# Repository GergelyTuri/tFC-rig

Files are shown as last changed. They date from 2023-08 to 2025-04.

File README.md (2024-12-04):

# Open source trace fear conditioning apparatus for rodents

## Project Description

The ability to form declarative memories declines with normal aging, as well as with aging-associated cognitive and emotional disorders. Diminished temporal binding capacity, which normally allows for the association of non-overlapping stimuli and events in an experience, is a core process underlying such impairment with aging. This project will identify aging-associated alterations in brain activity functions supporting temporal binding capacity, with the long-term aim of identifying potential targets to slow or alleviate cognitive and emotional impairments in aging and aging-associated neuropsychiatric disorders.

The temporal binding of emotionally salient stimuli and events has long been studied experimentally using trace fear conditioning (tFC). Here, subjects learn to associate a neutral auditory cue (conditioned stimulus, CS) with an aversive unconditioned stimulus (US), despite their separation by a stimulus-free gap of tens of seconds. The ability to form associations across delays on this timescale during tFC is severely diminished with aging. Current models propose that either 'time cell' activity in the hippocampal CA1 area bridges the delay (1), or sparse ensembles of neurons emerge during learning to intermittently encode CS-information for temporal binding (2). However, the neural mechanisms underlying the age-related decline in temporal binding capacity remain unknown, giving rise to fundamental questions. What functional changes in neural activity occur with aging in the particular CA1 circuitry that encodes emotionally salient stimuli for temporal binding? What changes occur with aging in neural processes for consolidation of this information?

To address these questions we have developed a trace fear conditioning apparatus tailored for headfixed rodents. This rig has been engeineered to be both modular and flexible, allowing for easy customization and expansion. The rig is controlled by Arduino microcontrollers equipeed with sensors. The conditioning is done by airpuffs directed toward the snout of the animals. Multiple Arduinos can be used in a daisy-chain manner which allows for paralel data collection of multiple mice. The rigs can also be equipped with video cameras (currently sourced from [White Matter Inc.](https://white-matter.com/products/e3Vision)) to record the mice's facial expression throughout the training sessions. The data collection is controlled by a Python script that interfaces with the hardware via serial communication. The raw data is saved in JSON fromat.

## Repository Structure

The repository is organized as follows:

- The `Components` folder contains all the hardware designs for the rig. These include 3D printable parts, laser cuttable parts, and electronics schematics.
- the `Software` folder contains the Arduino code for the microcontrollers and the Python code for the data collection and analysis.
- the `Analysis` folder contains the code for the analysis of the data collected by the rig.

## Installation and Usage

### Arduino

The Arduino code is written in C++ and can be compiled and uploaded to the microcontrollers using the Arduino IDE. Details of the code are provided in the `README.md` file under the `Software/Rig` folder.

### Analysis source code

See the `README.md` file under the `Software/Analysis` folder for details on how to use the analysis pipeline.

## Local Development

Most of the analysis routies were optimized for running in Google Colaboratory notebooks. However the package can be installed for local development. To create it please download the latest Anaconda distribution. Then clone the repositioy and run the following commands as shown below:

```bash
cd tFC-rig
```

```bash
conda env create -f environment.yml
```

```bash
conda activate cued-fc
```

```bash
cd Analysis
```

```bash
pip install -e .
```

wich will install the custom analysis package in editable mode.

## References

1. Sellami A, Al Abed AS, Brayda-Bruno L, Etchamendy N, Valerio S, Oule M, Pantaleon L, Lamothe V,
Potier M, Bernard K, Jabourian M, Herry C, Mons N, Piazza PV, Eichenbaum H, Marighetto A. Temporal
binding function of dorsal CA1 is critical for declarative memory formation. [Proc Natl Acad Sci U S A.](https://www.pnas.org/doi/10.1073/pnas.1619657114)
2017;114(38):10262-7. doi: 10.1073/pnas.1619657114. PubMed PMID: 28874586; PMCID: PMC5617244.
2. Ahmed MS, Priestley JB, Castro A, Stefanini F, Canales ASS, Balough EM, Lavoie E, Mazzucato L, Fusi
S, Losonczy A. Hippocampal Network Reorganization Underlies the Formation of a Temporal Association
Memory. [Neuron.](https://pubmed.ncbi.nlm.nih.gov/32392472/) 2020;107(2):283-+. doi: 10.1016/j.neuron.2020.04.013. PubMed PMID:
WOS:000551381900002.

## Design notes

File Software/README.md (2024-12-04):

# Arduino Sketch for Performing Trace-Fear Conditioning

Graphical representation of the trace-fear conditioning protocol:

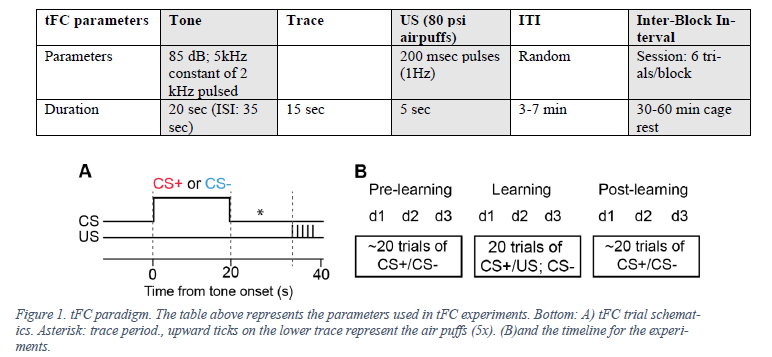
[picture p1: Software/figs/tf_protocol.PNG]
Trace-fear conditioning protocol


### Hardware Components

The Arduino controls the following components:

- 2 speakers which play two different tones (`CS+` and `CS-`)
- One water solenoid valve which delivers a water drop throughout the trial
- One air solenoid valve which delivers a series (5x) of airpuffs at the end of `CS+` the trial 
- Lickport which delivers a water drop when the mouse licks it

### The arduino records the following events:

- Times the mouse licks the lickometer

The trials make up blocks. 
One block consists of 3 trials of `CS+` and 3 trials of `CS-` in random order with random inter trial intervals (ITIs) between them.

### Development Environment

The code was developed in a conda environment. To create it please follow the instructions in the README.md file in the root directory.

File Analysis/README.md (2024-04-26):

# Trace Fear Conditioning Analysis Pipeline

This `Analysis` folder contains code supporting the cleanup and analysis of data generated by the trace fear conditioning rig.

## Source Code

Analysis pipeline source code exists at `Analysis/tfcrig` and in a Google Colaboratory notebook the `Analysis` directory is added to the system path so that pipeline code is imported in this way:

```python
from tfcrig.path.to.module import SomethingUseful
```

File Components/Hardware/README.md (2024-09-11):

# Reqired hardware components

* two speakers
* water solenoid
* air solenoid
* lickport (metal tube, usualy we use gavage needles)
* Arduino Uno with USB cable
* Arduino [Shield OM1](https://claylacefield.wixsite.com/openmazehome/pcb-designs) is preferred (03/22/2022 design) bc of the JST connetors, OM2 is also possible
* 12V power supply
* buttons, resistors, H-bridges, wires for shield assembly

| Item Name | Model |Vendor | Cat. number | link |
|---|---|---|---|---|
|speakers |Dayton Audio PC68-4 2-1/2" Full-Range Poly Cone Driver| Amazon |n/a |https://www.amazon.com/Dayton-Audio-PC68-4-Full-Range-Driver/dp/B0751FW9NP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
|air solenoid|SMC VK332-6G-01T valve, sol, body ported, 3 PORT SOLENOID VALVE|SMC Pneumatics|VK332-6G-01T|https://www.smcpneumatics.com/VK332-6G-01T.html
|liquid solenoid|Series 3 - Inert Solenoid ValveModerate - PEEK Body, EPDM Diaphragm2 Way Normally Closed1/8 Barbs120.078""|Parker Hannifin|003-0218-900|https://ph.parker.com/us/en/product/series-3-miniature-inert-liquid-valve/003-0218-900
|Arduino Uno|ELEGOO UNO R3 Board ATmega328P|Amazon|B01EWOE0UU |https://www.amazon.com/ELEGOO-Board-ATmega328P-ATMEGA16U2-Compliant/dp/B01EWOE0UU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
|Arduino Shield|OpenMaze|  OM1 | this repo|
|12V power supply|9VDC 1A Arduino Compatible Power Supply Adapter 110V AC 5.5 x 2.1mm Tip Positive|Amazon|Part#LJH -186|https://www.amazon.com/Arduino-Power-Supply-Adapter-110V/dp/B018OLREG4
|buttons|12Pcs 1A 250V AC 2 Pins SPST Momentary Mini Push Button Switch Normal Open (Pack of 12) CYT1078|Amazon|B0752RMB7Q|https://www.amazon.com/Cylewet-Momentary-Button-Switch-CYT1078/dp/B0752RMB7Q
|H-bridges|BOJACK 16-pin IC Stepper Motor Drivers Controllers L293 L293D|Amazon|N/A|https://www.amazon.com/BOJACK-16-pin-Stepper-Drivers-Controllers/dp/B09NBQVYLL
|Lickdetection|SparkFun Capacitive Touch Breakout |SparkFun|AT42QT1010|https://www.sparkfun.com/products/12041
|Lickport|Reusable AFN 20g x 1.5", 2.25mm-Curved|Cadence Science|7910|https://www.cadencescience.com/needles/animal-feeding/reusable-curved/reusable-afn-20g-x-1.5-inch-2.25mm-curved

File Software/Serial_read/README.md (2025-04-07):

# Pyhton scripts for data collection

## Overview

This folder contains two scripts which can perform data collection. The `py_arduino_serial.py` script is the one of main scripts which could be used if camera recording is not needed. The `py_arduino_serial_camera.py` script is a script which can be used when the White Matter cameras are connected to the recording setup and video footage is needed. The headers of these scripts also contain instructions on how to use them.

## Installation

The installation and functionalities tested on PC with Windows 10 operating system. 

### Prerequisites

Before proceeding with the installation, ensure you have the following prerequisites installed on your system:

* Git: Needed to clone the repository from GitHub.
* Conda: Used to create and manage the project environment. You can use either Anaconda or Miniconda. If you don't have Conda installed, you can download it from the official Conda website.
* Arduino-cli: Needed to update arduino files. This can be downloaded here: https://arduino.github.io/arduino-cli/0.35/installation/

### Installation Steps

Follow these steps to set up the project environment and start using the package:

1. Clone the GitHub Repository
First, clone the repository containing the project to your local machine. Open a terminal or command prompt and run the following command, replacing [Your-Repo-URL] with the URL of your GitHub repository:

    ``` bash
    git clone https://github.com/GergelyTuri/tFC-rig.git
    cd [Your-Repo-name/Software]
    ```

2. Create the Conda Environment

    ```bash
    conda env create [-n <environment_name>] -f environment.yml
    ```

3. Activate the Environment

    ```bash
    conda activate cued-fc
    ```
    
4. Install Arduino-cli at https://arduino.github.io/arduino-cli/0.35/installation/. 
Install it in a directory already in your PATH or add the Arduino CLI installation path to your PATH environment variable. This ensures your system will be able to detect and use it.

Environment Variables
Windows:
a. Go to your  windows search bar at the bottom of the screen and look up "Edit the system environment variables"
b. Click "Environment variables", then click edit "Path" variable under "user variables". 
c. Simply add the path to your arduino-cli software, save, and restart your vscode.

Mac:
a. Edit one of these files: ~/.bashrc or ~/.bash_profile.
b. Enter the file with nano ~/.bashrc, or through your file explorer
c. either add this new line or append the new path to your PATH variable:
            export PATH="{arduino-cli path}"
d. Save the changes (in nano this is ctrl-0, then hit enter) and restart vscode

If the sketch fails to update, test if the package can detect your connected board with:
```arduino-cli board list --format json
```
If given an error you may have to update the package with:
```arduino-cli update
arduino-cli core update-index
```

## Usage

### GUI

1. Open an Anaconda terminal, activate the environment and navigate to the `tFC-rig` folder.
2. Run the following command to activate the GUI. 

```bash
python -m Software.Serial_read.py_arduino_serial_GUI
```
This will run the `py_arduino_serial_camera` script (behavior recording with camera) when you submit

### Behavior recording without camera

1. Open an Anaconda terminal, activate the environment with "conda activate condaenv" and navigate to the `Software/Serial_read` folder. (View conda envs with "conda info --envs" and verify installed packages with "conda list")
2. Run the following command for further instructions:

    ```bash
    python py_arduino_serial.py -h
    ```

### Behavior recording with camera

1. Open an Anaconda terminal, activate the environment and navigate to the `tFC-rig` folder.
2. Run the following command for further instructions:

    ```bash
    python -m Software.Serial_read.py_arduino_serial_camera.py -h
    ```

## Data

Data is saved in JSON format. The data is saved in a folder named `data` in the same directory as the script.

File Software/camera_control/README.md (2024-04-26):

# Camera control files

## Overview

Recording facial features of the mice during the sessions can provide further information on the behvaior. To this end, we use network-based cameras from White Matter Inc. This folder contains files for controlling and testing the cameras. Camera recording with the Arduino based rig control is implemented in the `py_arduino_serial_camera.py` script in the `Serial_read` folder.

To operate the White Matter cameras, additional software is needed which can be found on their [website](https://white-matter.com/products/e3vision/) along with the documentation.

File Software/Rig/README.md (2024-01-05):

# Arduino software components for the trace-fear conditioning rig

Upload `Rig.ino` to the Arduino. This is the main program that runs the rig.

## Rig Operation

The rig Arduino sketch works with the following stages:

1. Session has not started: rig is waiting for an input to start the session
    * No air puffs
    * No water available
    * No audio signals
1. Six trials with random inter-trial intervals: six trials, as defined in the top-level README, are run automatically by the rig, with a random inter-trial interval between each trial whose length is determined at runtime
1. Session has ended: rig does nothing, waiting for the Arduino to be stopped or reset
    * No air puffs
    * No water available
    * No audio signals

### Daisy-Chaining Rigs

The rig Arduino sketch has been written to be run in two overall modes:

* Primary
* Secondary

When running a `primary` rig, all peripherals are controlled as described elsewhere, _and_ a "secondary" signal is sent on `PIN_SECONDARY` when:

* The session starts (the button connected to the primary rig is pressed)
* Each trial starts (each inter-trial interval ends)

When running a `secondary` rig, the `PIN_BUTTON` is not connected, and instead `PIN_SECONDARY` is used to determine when:

* The session starts
* Each trial starts

Follow these steps to configure multiple boards:

1. Setup the hardware on the primary rig. Ensure all peripherals (lick sensor, water solenoid, positive tone speaker, negative tone speaker, air puff, session start button, and a connection on the secondary pin to as many secondary rigs, in parallel, as desired)
1. Setup the hardware on the secondary rig. There is no need to connect the button, speakers, or air puff. The pinout can be exactly the same, noting that the `PIN_SECONDARY` is an input pin during setup rather than an output pin
1. Upload the latest working rig sketch to the primary rig. Be sure to set `IS_PRIMARY_RIG` to `true` and be sure that all other trial parameters are set as desired based on whether the session is a training session or an experiment, and based on the trial design as discussed elsewhere
1. Upload the latest working rig sketch to the primary rig. Be sure to set `IS_PRIMARY_RIG` to `false`. All other settings should be identical
1. Connect the primary rig to the secondary rig(s) using the `PIN_SECONDARY` pin. This pin should be connected to the `PIN_SECONDARY` pin on the secondary rig(s) 

### Maximum Session Length

The maximum session length depends on:

* Trial duration
* Number of trials
* Maximum inter-trial interval length

With the following values originally described:

* 50 second trials
* 6 trials
* 5 minute maximum inter-trial interval

The maximum session length is 30 minutes. It is unlikely that all five inter-trial intervals, which are defined as a random value between 1 and 5 minutes, are exactly 5 minutes, and so the average session will be much shorter (the expected value is 17 minutes 30 seconds).

### Using the Rig for Training

It is valuable to habituate mice to the rig environment. There are a few variables that can be set in `trial.h` that may be useful to facilitate training (as well as debugging issues with the rig).

#### `WATER_REWARD_AVAILABLE`

Water is available to the mouse when certain conditions are met. It is then dispensed for a set time. Set this to `true` to enable water _when_ those conditions are met.

#### `USING_AUDITORY_CUES`

During each trial, a random auditory cue is played, and in the `CS+` case air puffs are sent towards the mouse. Set `USING_AUDITORY_CUES` to `false` to turn off _both_ the auditory signal playing, _and_ the air puffs.

#### `USING_AIR_PUFFS`

Set this to `false` to stop sending air puffs, whether or not we are using auditory cues (although if we are not using auditory cues, we will also not send air puffs based on the way the rig was designed).

### Attenuating Water Rewards

There are a few options for modifying how much, and how often, water is available to the mouse.

#### `WATER_DISPENSE_ON_NUMBER_LICKS`

Licks are recorded with a small timeout `LICK_TIMEOUT` between licks. Consecutive licks are counted, with a longer timeout `LICK_COUNT_TIMEOUT` to reset the lick counter. So, if the lick timeout is 100ms, but the mouse is licking continuously for 300ms, there are 3 licks counted. But then if the lick count timeout is 250ms and the mouse stops licking for the next 300ms, the lick counter is set back to 0.

For water to dispense, a set number of `WATER_DISPENSE_ON_NUMBER_LICKS` licks have to have occurred in a row. In the above example where the mouse licks continuously for 300ms (three licks counted), with water dispensed after `2` licks the water reward would become available 200ms into the mouse's 300ms licking. Increasing this value makes it more difficult to obtain the water reward.

#### `WATER_DISPENSE_TIME`

This controls how long water is dispensed for in milliseconds. That is, once the conditions for dispensing water are met, water is dispensed for a set time (to ensure some water is available to the mouse) based on this parameter. The amount of reward available _when_ the mouse is rewarded can be controlled by this parameter.

#### `WATER_TIMEOUT`

When the conditions for water dispensation are met, a water timeout counter starts, and `WATER_TIMEOUT` milliseconds must elapse before another reward is available. So, if the timeout is 700ms and water is dispensed for 200ms, but the mouse continues to meet the conditions for water dispensation (much licking), water is unavailable for 500ms. This timeout can be increased to attenuate the water available to the mouse.

#### Further Attenuation

The software running the rig can be modified to further prevent or attenuate the availability of the water reward, but the above parameters are considered sufficient at this time.

### Using the Rig for Experiments

#### First time setup

1. Set up the rigs as described above and connect the Arduio(s) to the computer running the data collection software.
1. Create a new Anaconda environment and install the dependencies listed in `requirements.txt`.
1. Activate the environment and the rig is ready to be used.

#### Running the rig

1. Open an Anaconda terminal, activate the environment and navigate to the `Software/Serial_read` folder.
1. Read the instructions in the `README.md` file in the `Serial_read` folder. Currently there are two scripts which can perform data collection. The `py_arduino_serial.py` script is the one of main scripts which could be used if camera recording is not needed. The `py_arduino_serial_camera.py` script is a script which can be used when the White Matter cameras are connected to the recording setup and video footage is needed. The headers of these scripts also contain instructions on how to use them.

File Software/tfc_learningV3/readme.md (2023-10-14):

Pin layout
| Pin | Function |volts |
| --- | --- | --- |
| Digital 2 | button/trigger in | 3.3v | 
| Digital 5* | water solenoid | 12V |
| Digital 4 | air solenoid | 12V |
| Digital 10* | CS+ tone | 3.3V |
| Digital 9* | CS- tone | 3.3V |
| Digital 12 | lickport | 3.3V |

* = PWM capable

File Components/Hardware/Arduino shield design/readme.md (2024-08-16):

# Note on the desing of the Arduino shield

This is a modified versoion of an OM1 Arduino shield designed by [OpenMaze](https://claylacefield.wixsite.com/openmazehome/pcb-designs). It can be ordered from any commercial PCB manufacturer like OSHPark, JLCPCB, PCBWay, etc., by uploading the zip file to their website.

- 8/7/24 updated OM1 version

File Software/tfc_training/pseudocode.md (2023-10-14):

# Pseudocode for the traiing phase of the t-FC 

* set timer to 0
* print out plock start
* prit out trial start 
* if millis() == 10    
   * pick CS+ or CS- randomly and return True 
   * While True and the time reaches the end of the cs period
   * print out the end of the trial
 * start an inter-trial interval
 * if the time reaches the end of the ITI
 * print out the end of the ITI
 * start a new trial

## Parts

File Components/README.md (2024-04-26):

# Components

This folder contains 3D printable parts.

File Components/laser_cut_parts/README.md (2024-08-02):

# Body Chamber Laser Cut Parts

The body chambers were cut using 1/8" plastic sheets. Designed by Yuecheng Shi.

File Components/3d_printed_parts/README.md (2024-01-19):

# 3D printed parts

## Notes

Most of the parts were printed with a resin printer (type) using the following settings:

- slicer: 
- layer height:
- etc

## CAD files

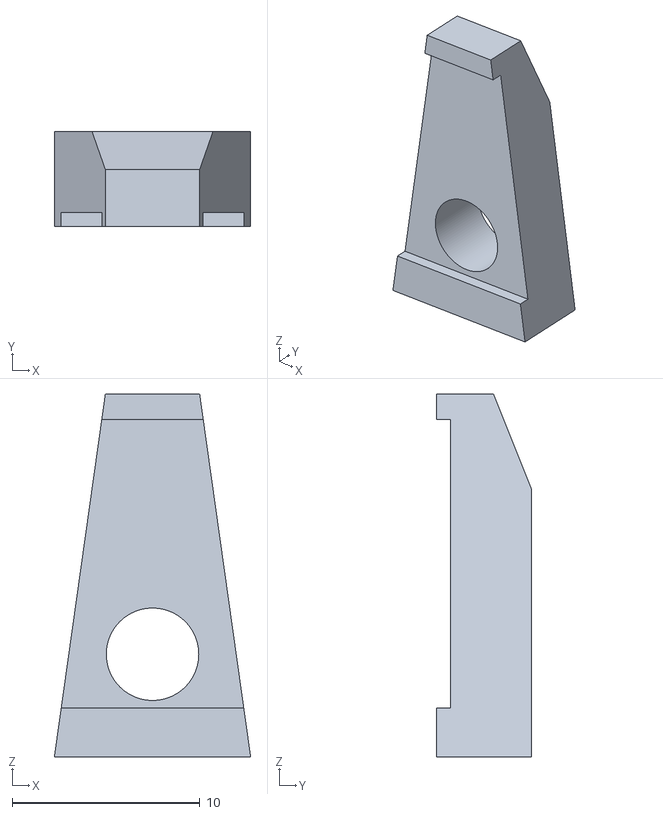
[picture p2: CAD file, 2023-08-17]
Components/3d_printed_parts/headpost_clamp/clamp_of_clamp_v2.stl
10.5 x 5.08 x 19.4

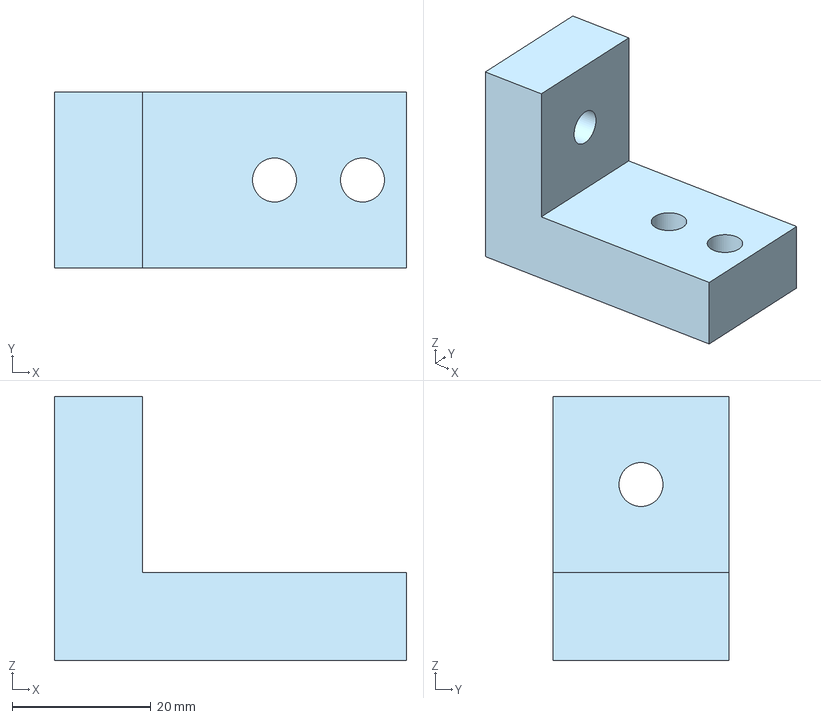
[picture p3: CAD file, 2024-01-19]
Components/3d_printed_parts/LED holder.step
50.8 x 25.4 x 38.1 mm

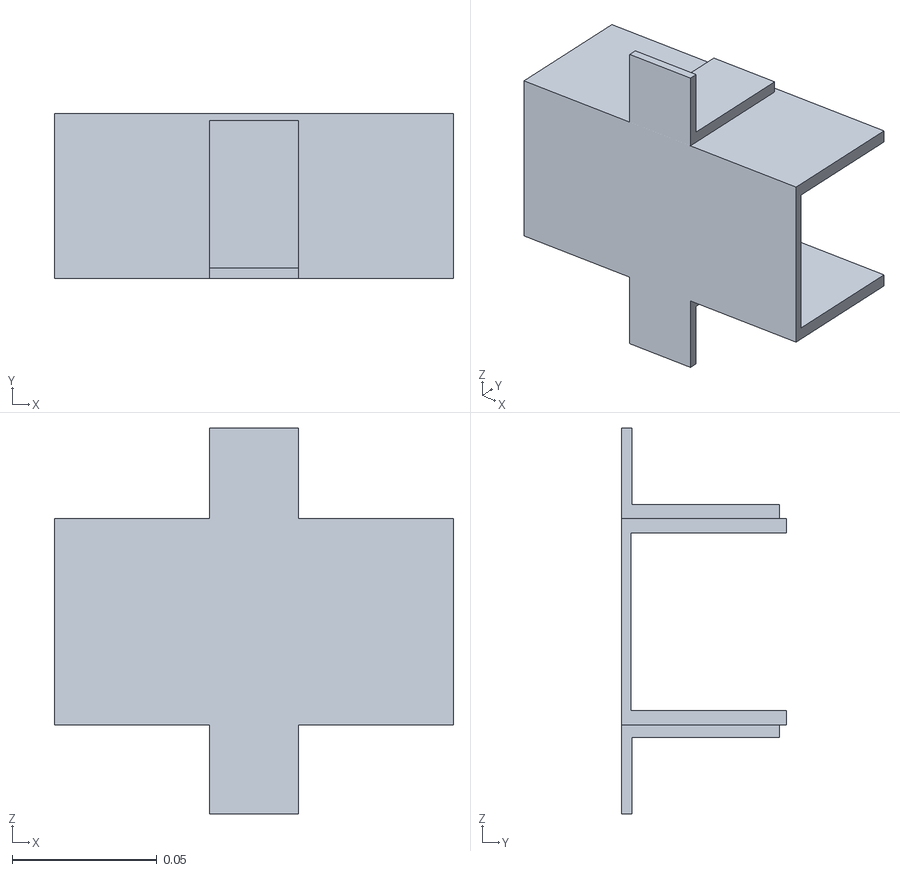
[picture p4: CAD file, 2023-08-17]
Components/laser_cut_parts/Body chamber_CL.obj
0.138 x 0.0569 x 0.133

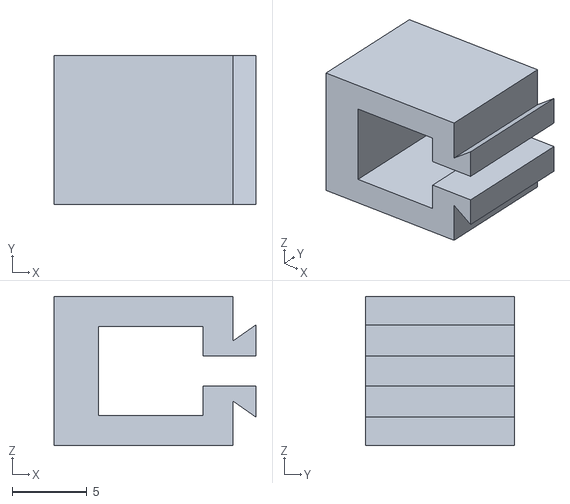
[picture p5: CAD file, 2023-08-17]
Components/3d_printed_parts/feeding needle holderV2.stl
13.6 x 10.0 x 10.0

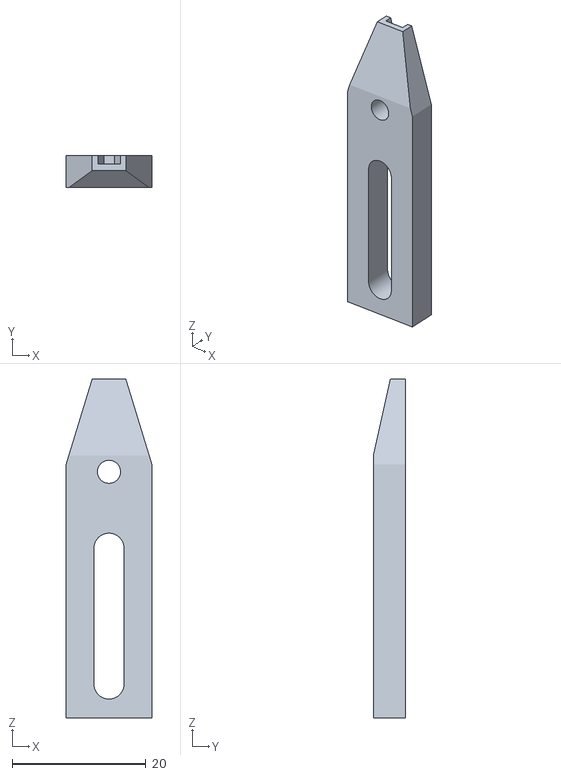
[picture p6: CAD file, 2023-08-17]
Components/3d_printed_parts/headpost_clamp/clamp_v2_1inch_slot.stl
12.8 x 4.83 x 50.7

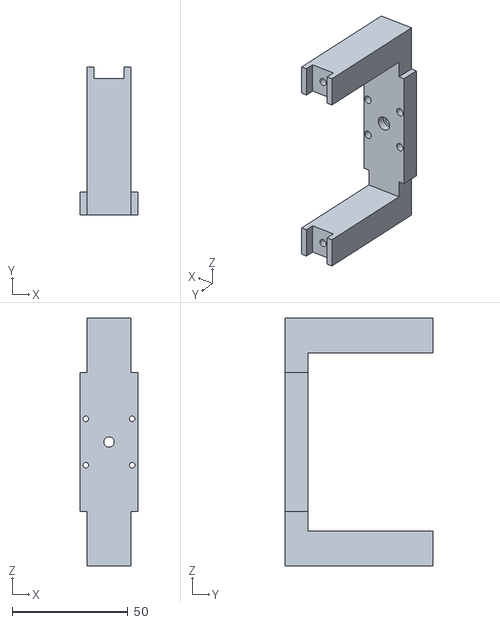
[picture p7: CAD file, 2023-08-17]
Components/3d_printed_parts/headpost_clamp/headpost holder_v2.stl
25.0 x 64.0 x 107.0

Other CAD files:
Components/3d_printed_parts/feeding needle holderV2.ipt
Components/3d_printed_parts/headpost_clamp/clamp_v2_1inch_slot_v1.ipt
Components/3d_printed_parts/headpost_clamp/clampholder_crimp.iam

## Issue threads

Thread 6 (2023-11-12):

trial number issue

GergelyTuri, 2023-11-12:
based on the recorded mock data it seems that the arduino actually sends out 7 trials not 6.

GergelyTuri, 2023-11-16:
after parsing one of the recocded files i see this:
```
Trial 1
 Event: 0: 4204: 0: Trial has started, 2023-11-15_10-56-11.239071
 Event: 0: 4236: 0: Printing trial parameters, 2023-11-15_10-56-11.293483
 Event: 0: 4277: 0: randomInterTrialInterval: 2372, 2023-11-15_10-56-11.348254
 Event: 0: 4322: 0: currentTrialType: 0, 2023-11-15_10-56-11.403883
 Event: 0: 19355: 15001: Negative signal start, 2023-11-15_10-56-25.748977
 Event: 0: 20356: 16002: Negative signal stop, 2023-11-15_10-56-26.739034
 Event: 0: 21356: 17002: Negative signal start, 2023-11-15_10-56-27.739370
 Event: 0: 22358: 18004: Negative signal stop, 2023-11-15_10-56-28.755059
 Event: 0: 23357: 19003: Negative signal start, 2023-11-15_10-56-29.756724
 Event: 0: 24358: 20004: Negative signal stop, 2023-11-15_10-56-30.744702
 Event: 0: 24387: 20034: Lick, 2023-11-15_10-56-30.808429
 Event: 0: 24388: 20034: Resetting lick count, 2023-11-15_10-56-30.862110
 Event: 0: 25358: 21004: Negative signal start, 2023-11-15_10-56-31.750980
 Event: 0: 26359: 22005: Negative signal stop, 2023-11-15_10-56-32.755693
 Event: 0: 27359: 23005: Negative signal start, 2023-11-15_10-56-33.755059
 Event: 0: 27663: 23309: Lick, 2023-11-15_10-56-34.070109
 Event: 0: 27664: 23310: Resetting lick count, 2023-11-15_10-56-34.123477
 Event: 0: 28360: 24006: Negative signal stop, 2023-11-15_10-56-34.758833
 Event: 0: 29360: 25006: Negative signal start, 2023-11-15_10-56-35.766064
 Event: 0: 30361: 26007: Negative signal stop, 2023-11-15_10-56-36.769789
 Event: 0: 31361: 27007: Negative signal start, 2023-11-15_10-56-37.757587
 Event: 0: 32362: 28008: Negative signal stop, 2023-11-15_10-56-38.758282
 Event: 0: 33362: 29008: Negative signal start, 2023-11-15_10-56-39.776004
 Event: 0: 34363: 30009: Negative signal stop, 2023-11-15_10-56-40.763340
 Event: 0: 35363: 31009: Negative signal start, 2023-11-15_10-56-41.778847
 Event: 0: 36364: 32010: Negative signal stop, 2023-11-15_10-56-42.769799
 Event: 0: 37364: 33010: Negative signal start, 2023-11-15_10-56-43.767469
 Event: 0: 37524: 33170: Lick, 2023-11-15_10-56-43.946775
 Event: 0: 37524: 33171: Resetting lick count, 2023-11-15_10-56-44.000639
 Event: 0: 37657: 33304: Lick, 2023-11-15_10-56-44.055719
 Event: 0: 38365: 34011: Negative signal stop, 2023-11-15_10-56-44.773942
 Event: 0: 38658: 34304: Resetting lick count, 2023-11-15_10-56-45.067543
 Event: 0: 41449: 37096: Lick, 2023-11-15_10-56-47.838123
 Event: 0: 41450: 37096: Resetting lick count, 2023-11-15_10-56-47.903999
 Event: 0: 41903: 37549: Lick, 2023-11-15_10-56-48.313135
 Event: 0: 42904: 38550: Resetting lick count, 2023-11-15_10-56-49.318430
 Event: 0: 47215: 42861: Lick, 2023-11-15_10-56-53.625218
 Event: 0: 47215: 42862: Resetting lick count, 2023-11-15_10-56-53.678905
 Event: 0: 48263: 43909: Lick, 2023-11-15_10-56-54.670584
 Event: 0: 48263: 43909: Resetting lick count, 2023-11-15_10-56-54.727529
 Event: 0: 48979: 44625: Lick, 2023-11-15_10-56-55.397165
 Event: 0: 49651: 45297: Lick, 2023-11-15_10-56-56.064331
 Event: 0: 49651: 45297: Water on, 2023-11-15_10-56-56.115558
 Event: 0: 49852: 45498: Water off, 2023-11-15_10-56-56.271090
 Event: 0: 50440: 46086: Lick, 2023-11-15_10-56-56.851571
 Event: 0: 50441: 46087: Water on, 2023-11-15_10-56-56.906782
 Event: 0: 50642: 46288: Water off, 2023-11-15_10-56-57.063173
 Event: 0: 51441: 47087: Resetting lick count, 2023-11-15_10-56-57.881798
 Event: 0: 54355: 50001: Trial has ended, 2023-11-15_10-57-00.779379
 Event: 0: 54355: 50002: Cleaning up last trial, 2023-11-15_10-57-00.838572
 Event: 1: 54369: 0: Water off via trial flush, 2023-11-15_10-57-00.893547
 Event: 1: 54410: 0: Puff stop via trial flush, 2023-11-15_10-57-00.951300
 Event: 1: 54452: 0: Positive signal stop via trial flush, 2023-11-15_10-57-01.004340
 Event: 1: 54505: 0: Negative signal stop via trial flush, 2023-11-15_10-57-01.060063
 Event: 1: 54558: 0: Waiting the inter-trial interval: 2372, 2023-11-15_10-57-01.115837
Trial 2
```

so it seems that counter changes after the trial ends
[mouse_74-5_2023-11-15_10-56-02.json](https://github.com/GergelyTuri/tFC-rig/files/13371533/mouse_74-5_2023-11-15_10-56-02.json)

Closed 2023-11-16.

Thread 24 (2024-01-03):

KeyboardInterrupt aka ctrl-c does not work during ITI

YuechengShi, 2024-01-03:
KeyboardInterrupt aka ctrl-c does not work during ITI

GergelyTuri, 2024-08-08:
@YuechengShi what's up with this?

YuechengShi, 2024-08-08:
Oh sorry didn’t see this.
When I press ctrl c during a trial it only stops the data collection but
not the arduino itself, which require me pressing the reset buttons on the
boards to end the trial.

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

GergelyTuri, 2024-08-08:
How often do you need/use this functionality?

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

YuechengShi, 2024-08-08:
I used ctrl c when we were running the serial read scripts directly through
anaconda. The GUI has a button to stop collecting data and end trials now
(which still requires me to manually reset both arduino boards).

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

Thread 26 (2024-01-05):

resetting arduinos before sessions

GergelyTuri, 2024-01-05:
Let's reset the arduino every time before the session starts to make sure everything is in a good state. See [this](https://arduinogetstarted.com/faq/how-to-reset-arduino-by-programming)
which does not seem to work. I think I don't get the logic. It resets the Arduino but then it does not run the setup function again. I also tried an implementation based on [watchdog timer](https://chat.openai.com/share/15c3ecfc-6d2a-4661-86cb-448098e0bf0f) but that did not work either. It resets the Arduino but then it does not run the setup function again. Maybe using the reset pin would work.

cpaynerogers, 2024-03-14:
Some context from Slack:

Actually, I just read a bit about it. Doing a software reset requires:

- Connecting an output pin to the reset pin on the board
- Sending that signal

So if we send the signal when we for example start the session ... the board will reset and we will have to press the session start again. And then the board will reset and we are stuck. What do you think instead about this logic:

1. The board, when reset, starts waiting for a session start button press
2. We also start a timer when the board starts
3. If that timer counts above a certain amount of millis like 5min, we trigger a board reset

This way if the boards are sitting running with no session, they periodically get refreshed. But if we want to ensure they are refreshed right before a session we should instruct the researcher to press the reset button on all board.

Separately, after a session is over, do you recommend a similar situation, where we start a session ended timer, and after 5min we reset the board?

This was implemented here: <https://github.com/GergelyTuri/tFC-rig/pull/17>. Assigning this issue to @GergelyTuri to see if:

- There have been any issues with this?
- We still want to try to pursue alternative or additional reset strategies?

GergelyTuri, 2024-03-21:
I like the periodic reset option. let's implement that.

Closed 2024-08-08.

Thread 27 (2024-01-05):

creating a proper anaconda environment

GergelyTuri, 2024-01-05:
Need to create a proper anaconda environment for running the python scripts. this requires a `requirements` or `environment.yml` file. The current environment file is specific to linux which makes installation difficult.

cpaynerogers, 2024-03-21:
@GergelyTuri I got setup on my Windows computer at home and I was able to install a Conda environment using our `Software/environment.yml` without any issues. Can you provide more specific details for this GitHub issue when you have a chance? Happy to help if I can

```text
(cued-fc) C:\Users\colin\Desktop\proj\tFC-rig\Software>conda env list
# conda environments:
#
base                     C:\Users\colin\anaconda3
cued-fc               *  C:\Users\colin\anaconda3\envs\cued-fc

(cued-fc) C:\Users\colin\Desktop\proj\tFC-rig\Software>conda list
# packages in environment at C:\Users\colin\anaconda3\envs\cued-fc:
#
# Name                    Version                   Build  Channel
bzip2                     1.0.8                hcfcfb64_5    conda-forge
ca-certificates           2024.2.2             h56e8100_0    conda-forge
colorama                  0.4.6                    pypi_0    pypi
intel-openmp              2024.0.0         h57928b3_49841    conda-forge
libblas                   3.9.0              21_win64_mkl    conda-forge
libcblas                  3.9.0              21_win64_mkl    conda-forge
libffi                    3.4.2                h8ffe710_5    conda-forge
libhwloc                  2.9.3           default_haede6df_1009    conda-forge
libiconv                  1.17                 hcfcfb64_2    conda-forge
liblapack                 3.9.0              21_win64_mkl    conda-forge
libsqlite                 3.45.2               hcfcfb64_0    conda-forge
libxml2                   2.12.6               hc3477c8_0    conda-forge
libzlib                   1.2.13               hcfcfb64_5    conda-forge
mkl                       2024.0.0         h66d3029_49657    conda-forge
numpy                     1.24.4           py38h1d91fd2_0    conda-forge
openssl                   3.2.1                hcfcfb64_1    conda-forge
pandas                    2.0.3            py38hf08cf0d_1    conda-forge
pip                       24.0               pyhd8ed1ab_0    conda-forge
pthreads-win32            2.9.1                hfa6e2cd_3    conda-forge
pyserial                  3.5                      pypi_0    pypi
python                    3.8.19          h4de0772_0_cpython    conda-forge
python-dateutil           2.9.0              pyhd8ed1ab_0    conda-forge
python-tzdata             2024.1             pyhd8ed1ab_0    conda-forge
python_abi                3.8                      4_cp38    conda-forge
pytz                      2024.1             pyhd8ed1ab_0    conda-forge
setuptools                69.2.0             pyhd8ed1ab_0    conda-forge
six                       1.16.0             pyh6c4a22f_0    conda-forge
tbb                       2021.11.0            h91493d7_1    conda-forge
tk                        8.6.13               h5226925_1    conda-forge
tqdm                      4.66.1                   pypi_0    pypi
ucrt                      10.0.22621.0         h57928b3_0    conda-forge
vc                        14.3                hcf57466_18    conda-forge
vc14_runtime              14.38.33130         h82b7239_18    conda-forge
vs2015_runtime            14.38.33130         hcb4865c_18    conda-forge
wheel                     0.42.0             pyhd8ed1ab_0    conda-forge
xz                        5.2.6                h8d14728_0    conda-forge
```

GergelyTuri, 2024-03-21:
thanks, i, too, tried this yesterday on a PC and it worked. will close this.

Closed 2024-03-21.

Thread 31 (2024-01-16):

creating proper conda package

GergelyTuri, 2024-01-16:
The current conda `environment.yml` file is specific to linux and does not work with Windows computers. This makes installation difficult on different systems.

cpaynerogers, 2024-03-14:
I am going to close this issue as duplicated by <https://github.com/GergelyTuri/tFC-rig/issues/27>

Closed 2024-03-14.

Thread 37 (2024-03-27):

adding lick-training functionality

GergelyTuri, 2024-03-27:
We need a training program for the mice which makes them to learn that the waterspout delivers water upon licking. This should be a just a simplified version of the "regular" trials, i.e.  one ~15-20  min long single trial where only the lick port is activated with the usual reward parameters (i.e. the reward params described [here](https://github.com/GergelyTuri/tFC-rig/tree/main/Software/Rig#attenuating-water-rewards) ) and the mouse receives reward based on these settings.
Alternatively, we can keep the same trial structure and just block sound and puff. The functionality  for this seems to be implemented already.
Ideally this option should be added to the GUI with a checkbox or something.

GergelyTuri, 2024-07-30:
upon further inspection, it seems that this functionality _almost_ works by simply tweaking the trial parameters. we had luck achieving a 30-40 min trial by adjusting `NUMBER_OF_TRIALS` and `TRIAL_DURATION` variables in the `trial.h` file. the only issue we are having right now, is that the messages do not print or get saved in the json file from the secondary rig. the primary rig works fine. we will:
- test the secondary rig's arduino to see if this is due to a faulty serial port

Closed 2024-08-08.

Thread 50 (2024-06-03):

enhancing flexibility by adding a trial class

GergelyTuri, 2024-06-03:
The training/recording functionality should be a bit more flexible. This could be done creating a `trial_type` class where new trial patterns could be defined then any of these defined trial type could be called from the main program through the GUI.

Currently we have the following trial types:
- type1
- type2

These should be the "base types" where the two different tones are played and the reward is available throughout the whole trial (no airpuff tho).  we should add on something like "puffed_type1" and "puffed_type2" where the tone is on, reward is on but there is the 5x airpuff at the end of the trial. this could facilitate the analysis as well, because the trials where the airpuff actually happend could be easier to grab.

Other trial types which should be implemented:
"delayed_reward" when the reward is only available at the end of the tone following a delay (i.e. trace) interval. ideally this delay can be changed within a certain reange (e.g. 1-10 s following the end of the tone.)

GergelyTuri, 2024-06-19:
we also need a trial type where the tone is on but there is no reward at all.

schaefer30037, 2024-07-30:
Implemented four trial types:
`'no_puff_CS+', 'no_puff_CS-', 'puff_CS+', 'puff_CS-'`

schaefer30037, 2024-07-31:
Lick training class added to GUI

GergelyTuri, 2024-08-08:
these seem to be working as of 8/8/24

Closed 2024-08-08.

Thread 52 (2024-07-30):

Debug increased number of trials

schaefer30037, 2024-07-30:
Currently the maximum number of trials is set to 16. We would like to increase the number of trials up to 30.

When setting the NUMBER_OF_TRIALS higher, some of the variables don't print out either in the GUI or the json file. It's tough to identify the root cause, but it's possible there is some sort of memory overflow or buffer overflow issue.

For a potential fix, the `trialTypes` int array should be changed to a char array.

schaefer30037, 2024-07-31:
Splitting into smaller strings resolves the bug, though the underlying core problem is still unclear. Using string casting in print statements (ex:  `Serial.println("Session consists of " + String(NUMBER_OF_TRIALS)`) is buggy. Doing 50 trials is also buggy.

GergelyTuri, 2024-08-08:
i believe that this works now to the extend we need it to be working. no extremities were tested but we can go up to a reasonable number of trials without any issues (8/8/2024)

Closed 2024-08-08.

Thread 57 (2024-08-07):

arduino-cli code update

schaefer30037, 2024-08-07:
arduino-cli command line tool has an update. When we do update it, there are two lines of code that need to be changed.
- You can install the latest version from https://arduino.github.io/arduino-cli/1.0/installation/#latest-packages
- Ensure the latest version is installed (should be 1.0.3 or above) by running in command prompt: `arduino-cli version`

Then, in `Software\Serial_read\update_sketch.py`:
- `boards_info` should be updated to `boards_info['detected_ports']` around line 29 (the for loop)
- Add `cores_info = cores_info['platforms']` around line 44.

Verification:
- Run in command prompt: `arduino-cli board list --format json`. "detected_ports" should appear
- Run in command prompt: `arduino-cli core list --format json`. "platforms" should appear
- Verify code changes by updating the sketch through the GUI

Context: We need this to compile and update our sketches dynamically. Arduino CLI is an all-in-one solution that provides Boards/Library Managers, sketch builder, board detection, uploader, and many other tools needed to use any Arduino compatible board and platform from command line or machine interfaces. ([Link](https://arduino.github.io/arduino-cli/0.35/))

GergelyTuri, 2024-08-08:
This seems to be a relatively low priority issue. Austin can take care of this when he is around. closing it for now.

Closed 2024-08-08.

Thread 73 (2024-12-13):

Finding solution to sync primary and secondary arduinos -- hardware upgrade

GergelyTuri, 2024-12-13:
_Problem:_
 the primary and secondary arduinos don't function in sync which leads to a few hundred ms delay in their operation. This introduces some uncertainty in the analysis (e.g. [here](https://github.com/GergelyTuri/tFC-rig/issues/65)).

_Suggested solutions:_
There are a couple of solutions for this problem (Digital Sync Pulse, hardware interrupts) but the most stable and feasible one would be using an external Real Time Clock (RTC) device. This would require a hardware and software update but in turn, it would allow stable, long-term sync between devices. An example for this can be found [here](https://www.circuitbasics.com/how-to-use-a-real-time-clock-module-with-the-arduino/)

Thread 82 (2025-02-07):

Updated metrics

schaefer30037, 2025-02-07:
We want metrics (**raw licks** and **lick freq**) for:

**Pre-CS, Tone, Trace, Airpuff/postTrace, ITI**

We want this data across sessions and across trials (per trial). The image contains Pre-CS, Tone, Trace, and post Trace. ITI comes after

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

Also look into getting the duration of each section, this might be too tough(?)

Also need to fix normalization (can be done outside the pipeline). This is why we need metrics for each section

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

schaefer30037, 2025-03-07:
Analysis code and notebook updated to meet these requirements

Closed 2025-03-07.

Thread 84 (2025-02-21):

Switch between new and old rig

schaefer30037, 2025-02-21:
**TODO:** revisit issue in two weeks (we might not need this)

We need a way to switch back and forth between the old rig (puffs) and new rig (no puffs)
Currently main branch contains new rig

Potential solutions:
- Keep old design on another branch
- Separate rig file for old design, toggle between files in GUI
- Others(?)

GergelyTuri, 2025-03-05:
@schaefer30037 Colin latest PR is related to this. Can you please look into how it could be implemented in the GUI?

schaefer30037, 2025-03-07:
GUI works and experiment starts as expected

Closed 2025-03-07.

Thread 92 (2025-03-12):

GUI minor fixes

schaefer30037, 2025-03-12:
Output JSON even if trial hasn't started.

When selecting trial type investigate why the dropdown options are black

Current error message when ending experiment before trial starts:
`Traceback (most recent call last):
File "C:\Users\turilab-tfc\.conda\envs\cued-fc\lib\runpy.py", line 194, in _run_module_as_main
return _run_code(code, main_globals, None,
File "C:\Users\turilab-tfc\.conda\envs\cued-fc\lib\runpy.py", line 87, in _run_code
exec(code, run_globals)
File "C:\Users\turilab-tfc\Documents\tFC-rig\Software\Serial_read\py_arduino_serial_camera.py", line 227, in <module>
main()
File "C:\Users\turilab-tfc\Documents\tFC-rig\Software\Serial_read\py_arduino_serial_camera.py", line 218, in main
generate_pdf(file_path, header, data_list)
File "C:\Users\turilab-tfc\Documents\tFC-rig\Software\Serial_read\generate_pdf.py", line 96, in generate_pdf
fig = simple_lick_plot(df)
File "C:\Users\turilab-tfc\Documents\tFC-rig\Software\Serial_read\generate_pdf.py", line 18, in simple_lick_plot
df['Time (s)'] = (df['absolute_time'] - df.loc[session_index, 'absolute_time']).dt.total_seconds().astype(int)
File "C:\Users\turilab-tfc\.conda\envs\cued-fc\lib\site-packages\pandas\core\indexing.py", line 1096, in __getitem__
return self.obj._get_value(*key, takeable=self._takeable)
File "C:\Users\turilab-tfc\.conda\envs\cued-fc\lib\site-packages\pandas\core\frame.py", line 3877, in _get_value
row = self.index.get_loc(index)
File "C:\Users\turilab-tfc\.conda\envs\cued-fc\lib\site-packages\pandas\core\indexes\range.py", line 349, in get_loc
raise KeyError(key)
KeyError: nan`

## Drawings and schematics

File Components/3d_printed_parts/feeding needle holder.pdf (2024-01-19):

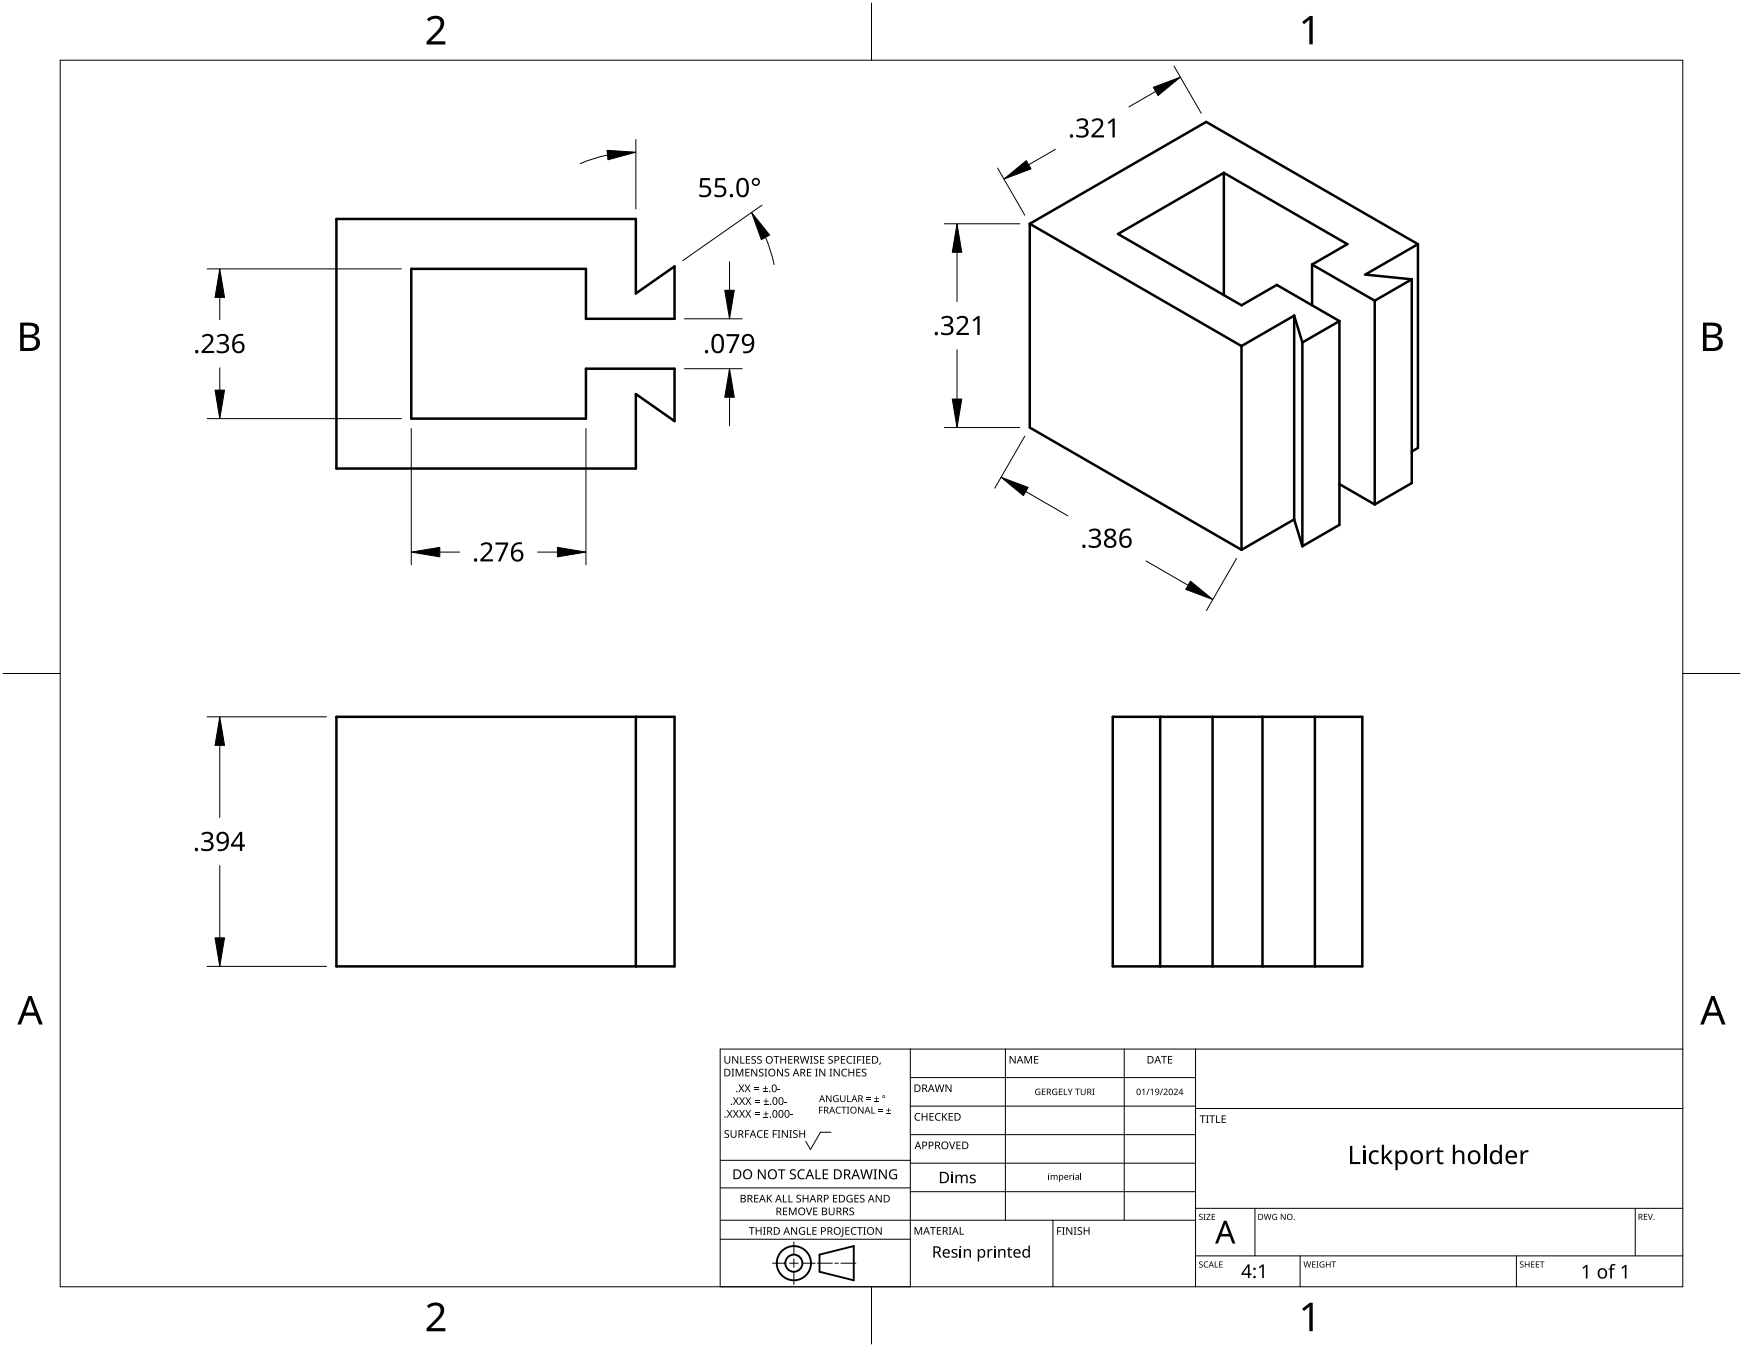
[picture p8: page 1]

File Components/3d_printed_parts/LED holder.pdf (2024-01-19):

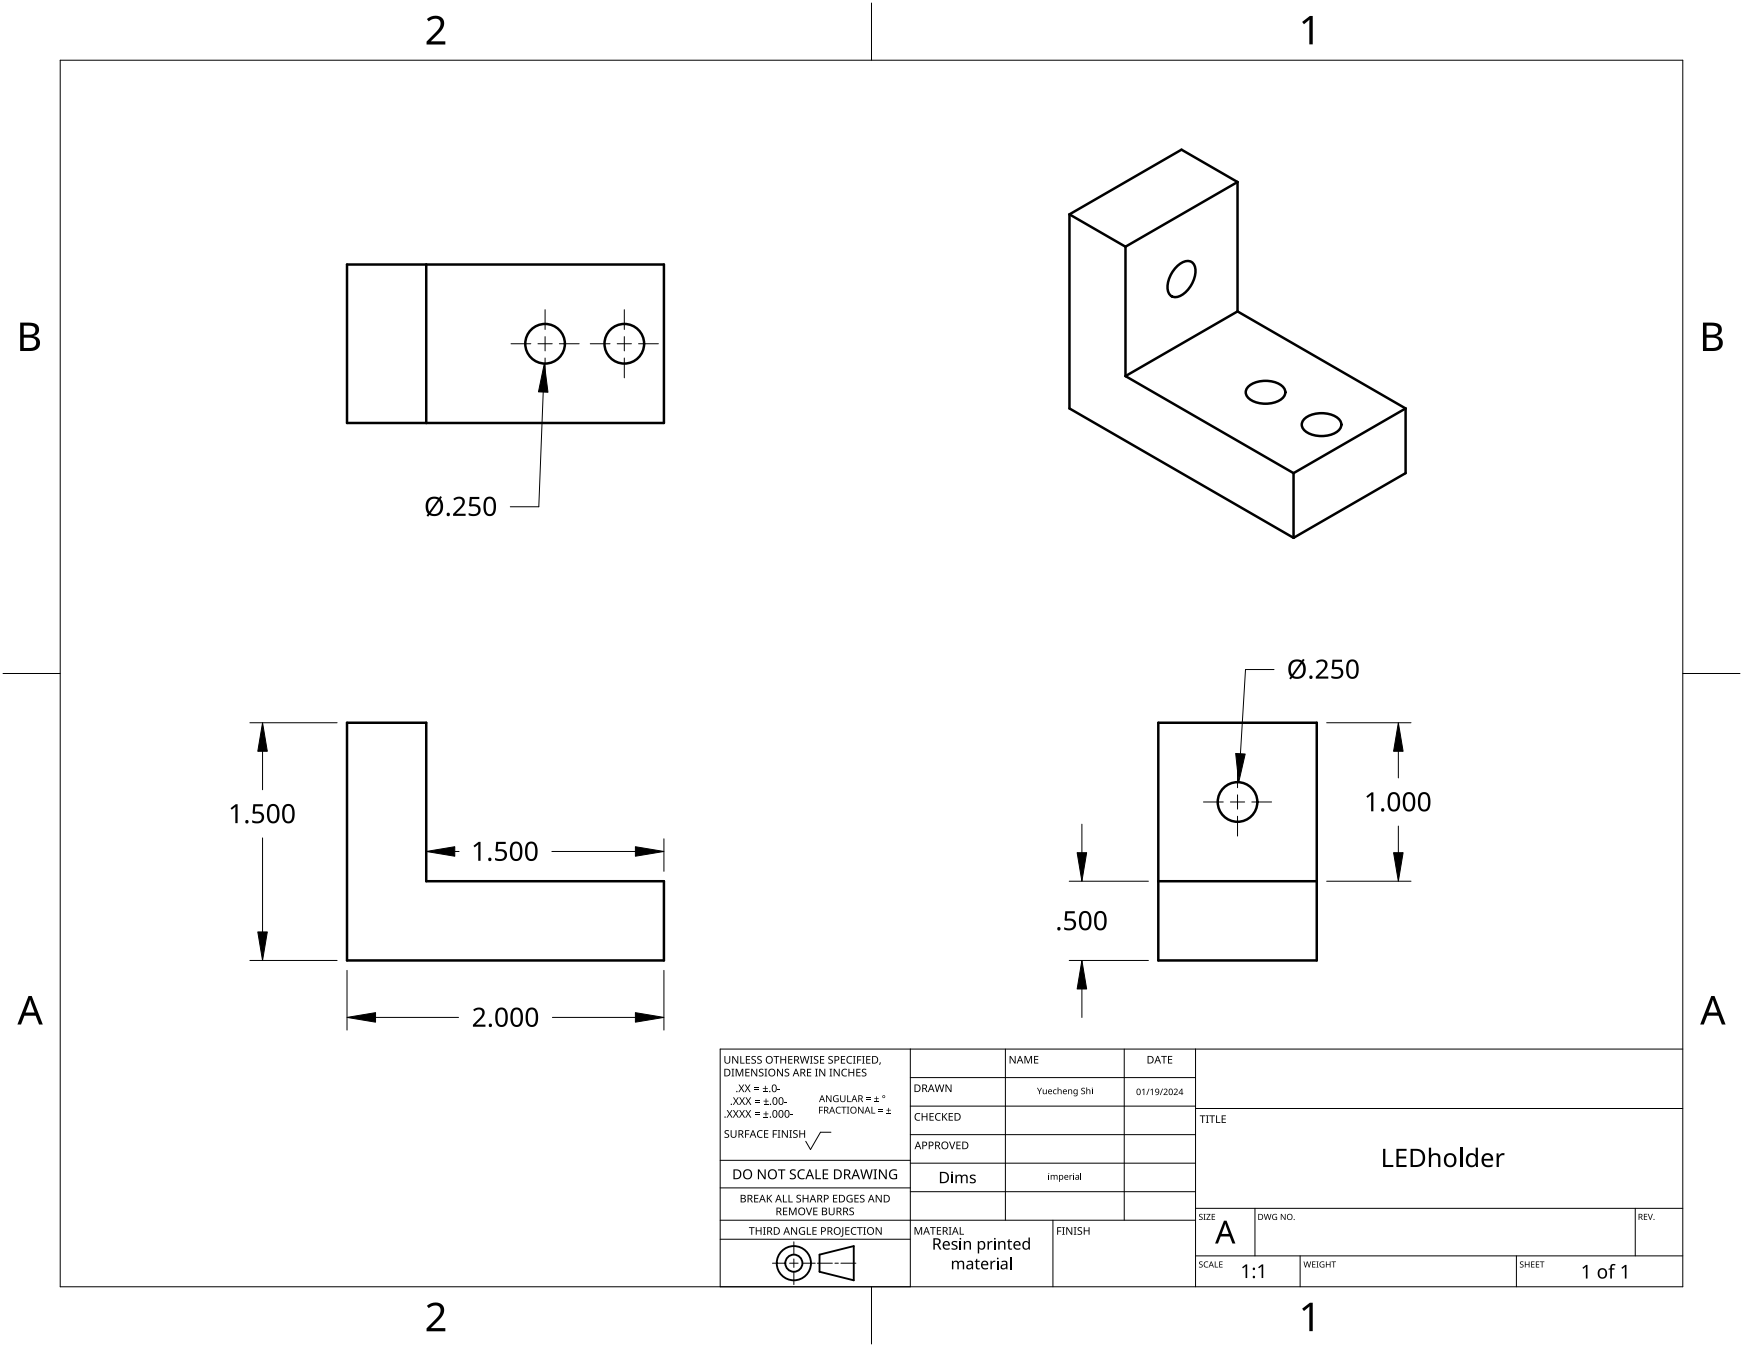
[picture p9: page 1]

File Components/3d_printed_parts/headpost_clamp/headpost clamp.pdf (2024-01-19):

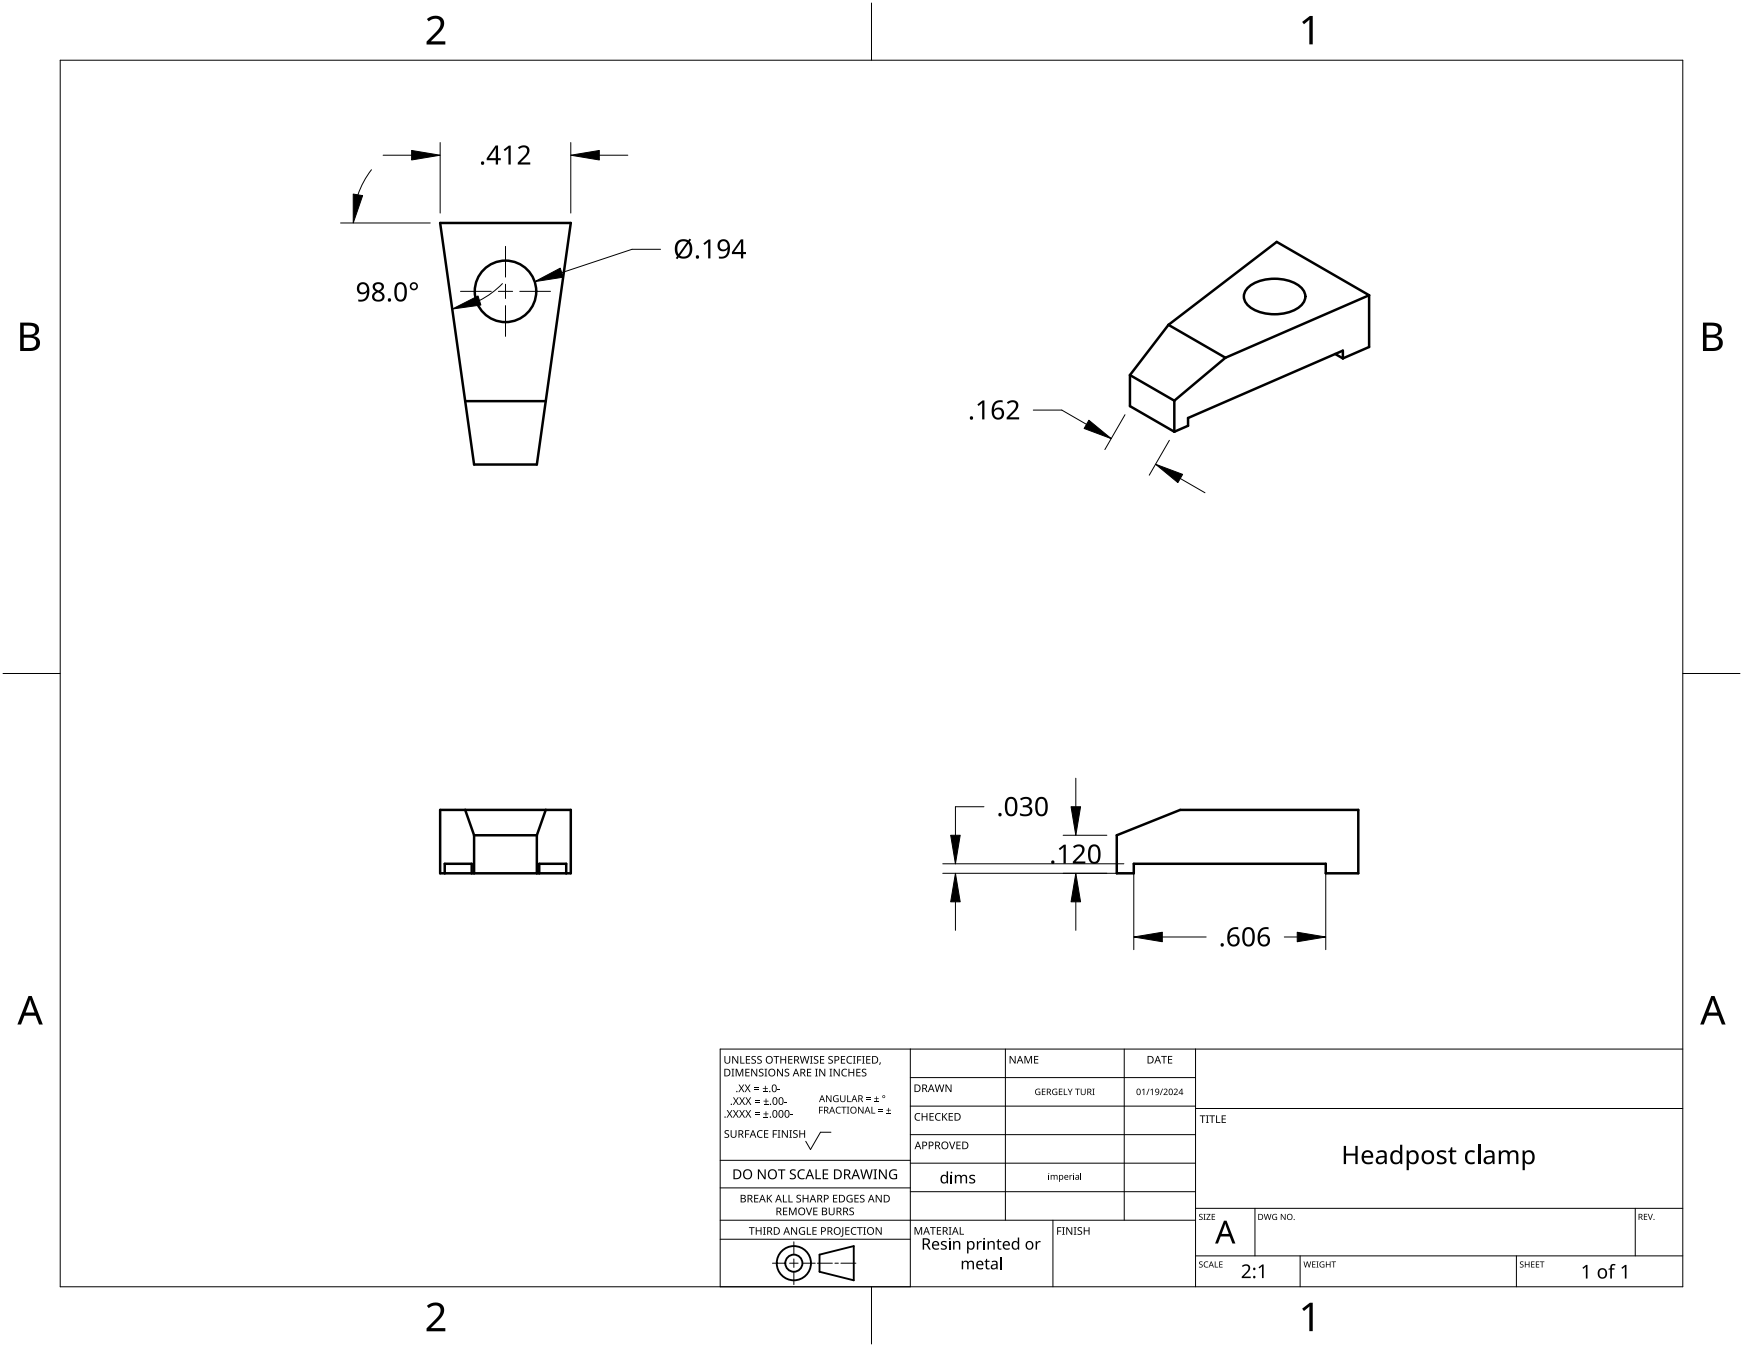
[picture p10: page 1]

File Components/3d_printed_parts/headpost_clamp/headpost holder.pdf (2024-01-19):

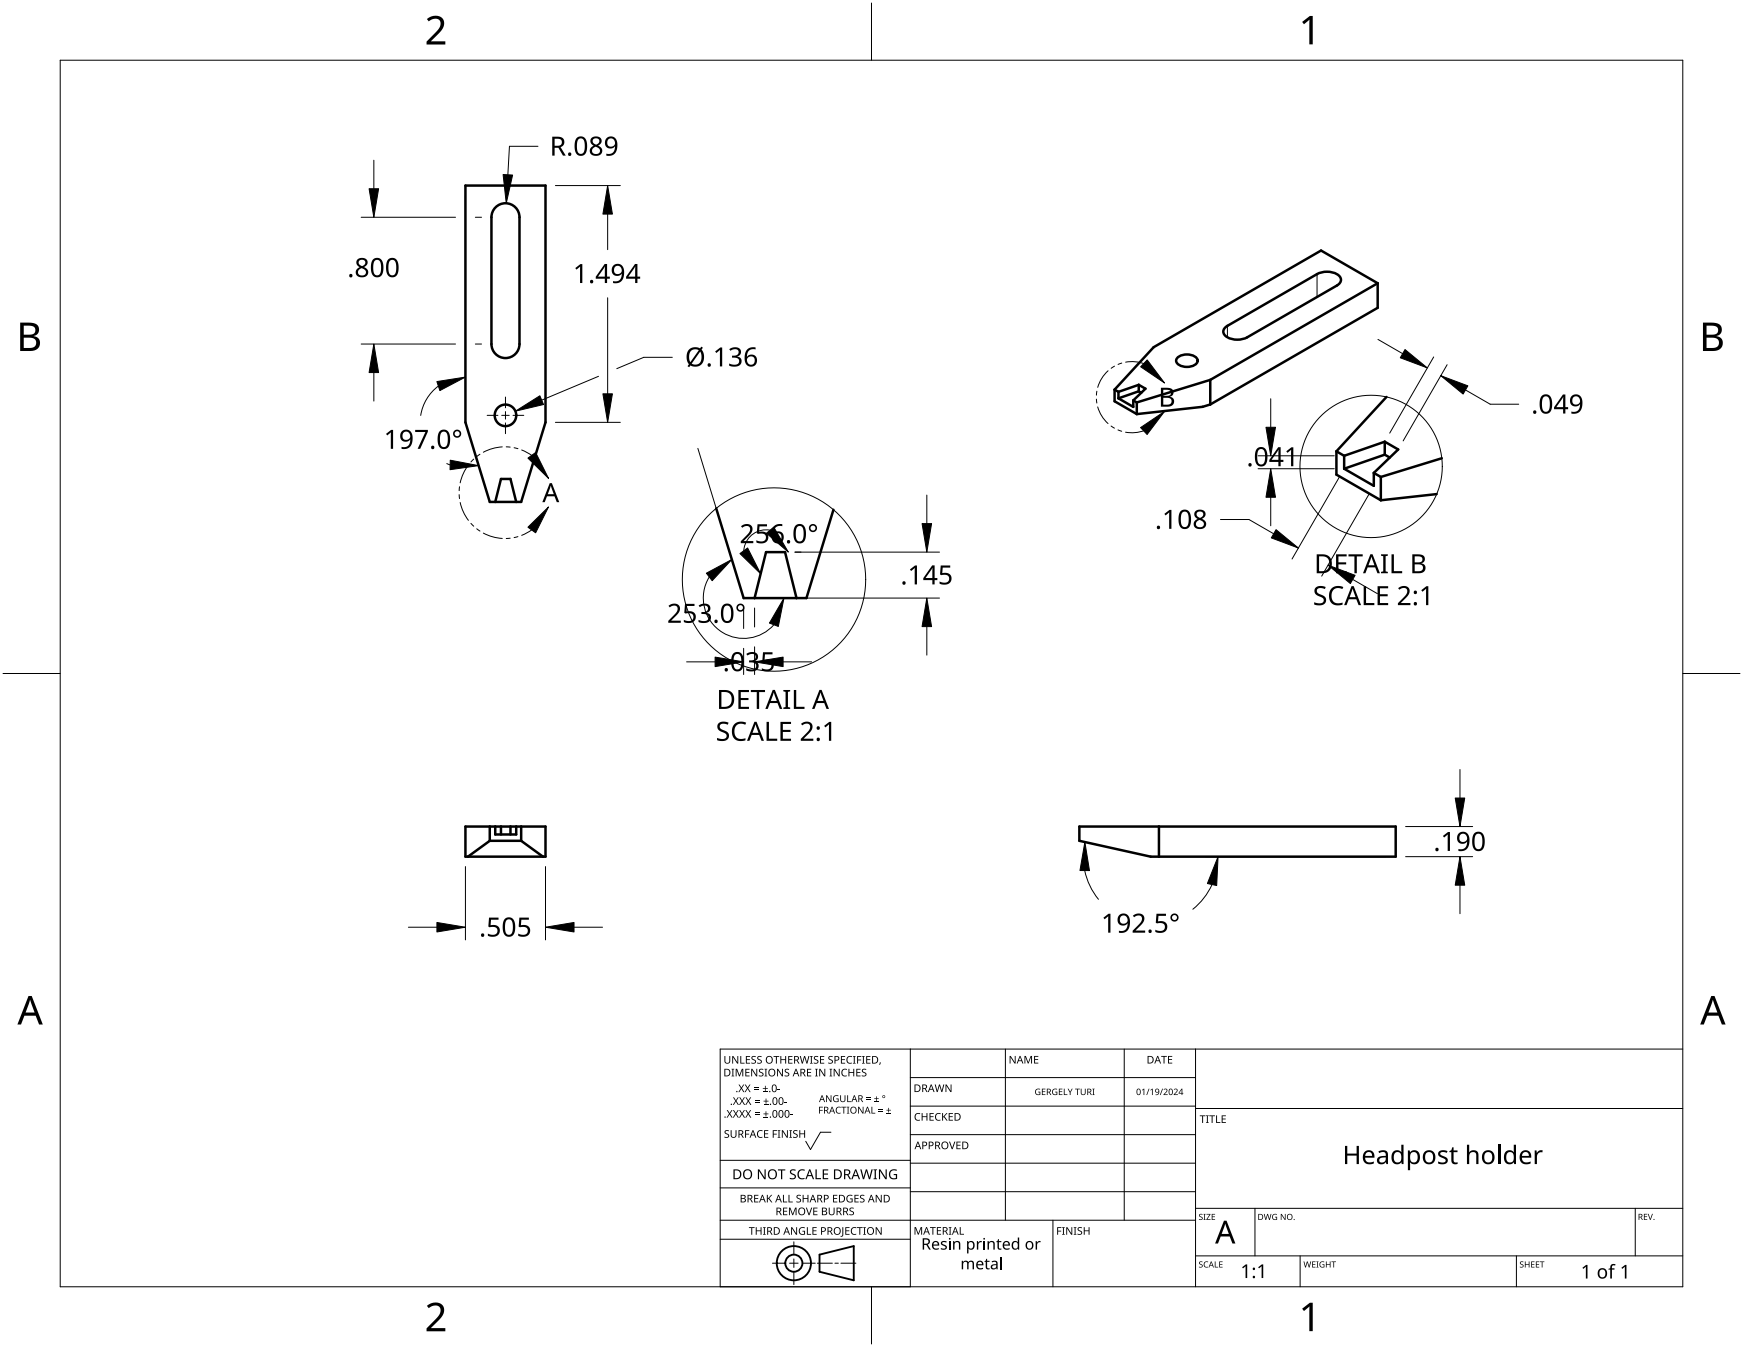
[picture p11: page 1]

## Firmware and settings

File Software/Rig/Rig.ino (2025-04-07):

/* Given that the Arduino is connected to components at the following pins:
 *
 * DIGITAL PINS
 * ============
 *  -  digital 4: Air puff
 *  -  digital 5: Water solenoid
 * 
 * ANALOG PINS
 * ===========
 *  -  9: Auditory cue (CS-)
 *  - 10: Auditory cue (CS+)
 *  - 11: Button to start trial
 *  - 12: Lick
 *  -  3: triggering camera recording also
 *  -  4: setting an LED to on during the trial
 *  -  6: Secondary pin (daisy chains)
 *  -  7: Reset pin (board connected to its own reset input)
 *
 * Defines a configurable run of the experimental rig with the following options:
 *
 *  - Choose to make water available
 *  - Deliver a positive or negative auditory signal
 *  - Deliver air puffs or not (positive auditory signal)
 *
 * The current implementation makes some assumptions:
 *
 *  - Each session is triggered with a button press
 *  - Air puffs are delivered at a fixed point in the trial
 *  - There are two auditory signals: positive and negative
 *    - Positive is a constant 5kHz tone
 *    - Negative is a pulsed 2kHz tone
 *  - Air puffs are only delivered after a positive auditory signal
 *
 * It can be improved by:
 *
 *  - Adding an `init.h` with the values we define at start
 *    (So they are not re-used in flush functions)
 *  - Consistency between "end" and "start" semantics
 *  - Check that differences in "global time" and "trial time" aren't
 *    going to cause any issues (some code "thinks" in global, other code
 *    "thinks" in trial, depending on requirements)
 *    - For example, refactor air puffs to use just one
 *  - The trial order randomization seems biased to start at trial 1
 *  - Refactor the top-level `loop` blocks into session functions, e.g.
 *    `preSessionReset`, `sessionStart`, `sessionEnd`, `postSessionReset`
 *
 */
#include "rig.h"
#include "trial.h"
#include "utils.h"

long rigStartTime = __LONG_MAX__;
bool sessionHasStarted = false;
long sessionStartTime = __LONG_MAX__;
bool sessionHasEnded = false;
long sessionEndTime = 0;

int trialTypes[NUMBER_OF_TRIALS];
char trialTypesChar[NUMBER_OF_TRIALS+1];
int currentTrialType;
int trialTypesCharIdxSize = sizeof(trialTypesCharIdx) / sizeof(trialTypesCharIdx[0]);
int trialType1Idx = getArrayIndex(TRIAL_TYPE_1, trialTypesCharIdx, trialTypesCharIdxSize);
int trialType2Idx = getArrayIndex(TRIAL_TYPE_2, trialTypesCharIdx, trialTypesCharIdxSize);

long randomInterTrialInterval = 0;

int currentTrial;
bool trialHasStarted = false;
long trialStartTime = __LONG_MAX__;
bool trialHasEnded = false;
long trialEndTime = 0;

long lastLickTime = 0;
bool isLicking = false;
int lickCount = 0;
long lastWaterTime = 0;

bool isPuffing = false;
long puffStartTime = __LONG_MAX__;
long puffStopTime = 0;

bool positiveSignalPlaying = false;
long positiveSignalStart = __LONG_MAX__;

bool negativeSignalPlaying = false;
long negativeSignalStart = 0;
long negativeSignalStop = 0;

void setup() {
  Serial.begin(BAUD_RATE);
  pinMode(PIN_AIR_PUFF, OUTPUT);
  pinMode(PIN_WATER_SOLENOID, OUTPUT);
  pinMode(PIN_TONE_NEGATIVE, OUTPUT);
  pinMode(PIN_TONE_POSITIVE, OUTPUT);
  pinMode(PIN_LICK, INPUT);
  pinMode(PIN_MOUSE_LED, OUTPUT);
  pinMode(PIN_CAMERA, OUTPUT);
  pinMode(PIN_RESET, OUTPUT);

  // Secondary pins are used to trigger "secondary" (vs. primary) rigs
  // in a daisy-chain setup. Just one is added until the primary-
  // secondary code is tested. Only the primary rig should use these
  // pins. The secondary rigs should have a connection to the primary
  // rig in place of the `PIN_BUTTON`. Because a button is `HIGH` by
  // default and `LOW` when pressed, the secondary pins are set to
  // `HIGH` here
  if (IS_PRIMARY_RIG) {
    // Add logic to skip positive and negative tones on secondary rigs
    // (need to keep water, licks, air puffs)
    pinMode(PIN_BUTTON, INPUT_PULLUP);
    pinMode(PIN_SECONDARY, OUTPUT);
  } else {
    // Configures the secondary pin the and does
    // not configure `PIN_BUTTON`
    pinMode(PIN_SECONDARY, INPUT);
  }

  // Each session of trials has a different random seed taken by
  // reading from a disconnected pin.
  randomSeed(analogRead(0));

  // Each session is a random permutation of the trial types (ex: {CS-, CS-, CS-, CS+, CS+, CS+}
  // in the case that there are `6` trials).
  // Note that 0 is CS-, 1 is CS+.
  for (int i = 0; i < NUMBER_OF_TRIALS / 2; ++i) {
    trialTypes[i] = trialType1Idx;
  }
  for (int i = NUMBER_OF_TRIALS / 2; i < NUMBER_OF_TRIALS; ++i) {
    trialTypes[i] = trialType2Idx;
  }
  currentTrialType = trialTypes[0];
  // This uses Fisher-Yates shuffle to randomize the trial types
  for (int i = NUMBER_OF_TRIALS-1; i > 0; --i) {
    int j = random (0, i+1);
    int temp = trialTypes[i];
    trialTypes[i] = trialTypes[j];
    trialTypes[j] = temp;
  }
  intArrayToChar(trialTypes, NUMBER_OF_TRIALS, trialTypesChar);

  // Keeps track of the rig start time. This should be close to 0 since
  // `millis` starts when the rig starts, but is tracked separately for
  // readability
  rigStartTime = millis();
}

void loop() {
  // Checks for a pre-session reset
  if ((!sessionHasStarted) && (!sessionHasEnded) && (millis() - rigStartTime > RIG_PERIODIC_RESET_TIME)) {
    rigSoftwareReset();
  }

  // Checks for the session start
  if (checkSessionStart() && (!sessionHasStarted) && (!sessionHasEnded)) {
    // Because this function has a delay to ensure the simulated button
    // press is sent to secondary rigs, call it all the time to avoid
    // drift between rigs
    simulateButtonPress();

    printSessionParameters();

    print("Session has started");
    sessionHasStarted = true;
    digitalWrite(PIN_CAMERA, HIGH);
    sessionStartTime = millis();
  }

  // The session loop. It executes all `n` trials with the
  // inter-trial wait period between trials.
  if (sessionHasStarted && !sessionHasEnded) {
    if (!trialHasStarted) {
      trialStart();
    } else {
      if (!trialHasEnded) {
        long currentTime = millis();
        long trialTime = currentTime - trialStartTime;

        // Core rig loop.
        // Executes continuously during each trial
        checkForTrialEnd();
        checkLick();
        if (WATER_REWARD_AVAILABLE && !TRAINING_TRIALS_ARE_REWARDED) {
          checkWater();
        }
        if (
          TRAINING_TRIALS_ARE_REWARDED &&                         // Are we giving water, not air?
          (trialTypeObjects[currentTrialType]->training==true) && // Is the current trial type a training trial?
          (trialTime >= AIR_PUFF_START_TIME) &&                   // Has the trace period started?
          (trialTime < AIR_PUFF_TOTAL_TIME + AIR_PUFF_START_TIME) // Is the trace period not over yet?
        ) {
          checkWater();
        }
        if (USING_AUDITORY_CUES && IS_PRIMARY_RIG) {
          if (trialTypeObjects[currentTrialType]->training==true) {
            // Water is made available at the point in the experiment where
            // an air puff used to be sent
            if (!TRAINING_TRIALS_ARE_REWARDED) {
              checkAir();
            }
          }
          if (trialTypeObjects[currentTrialType]->hasSignal==1){
            if (trialTypeObjects[currentTrialType]->signal == 1) {
              checkPositiveSignal();
            } else {
              checkNegativeSignal();
            }
          }
        }

        // Inter-trial interval
        if (trialHasEnded) {
          print("Cleaning up last trial");
          flushTrialMetaData();
          flushLickMetaData();
          flushAirPuffMetaData();
          flushPositiveSignalMetaData();
          flushNegativeSignalMetaData();

          // Use `randomInterTrialInterval` in the real trial. Use
          // `INTER_TRIAL_DEBUG_WAIT_INTERVAL` for debugging as it is set to
          // just one second
          long interTrialIntervalStartTime = millis();
          long interTrialIntervalWaitTime;
          if (DEBUGGING) {
            vprint("DEBUGGING: Waiting for", INTER_TRIAL_DEBUG_WAIT_INTERVAL);
            interTrialIntervalWaitTime = INTER_TRIAL_DEBUG_WAIT_INTERVAL;
          } else {
            if (currentTrial < NUMBER_OF_TRIALS) {
              vprint("Waiting the inter-trial interval", randomInterTrialInterval);
              interTrialIntervalWaitTime = randomInterTrialInterval;
            } else {
              vprint("Waiting after the last trial", POST_LAST_TRIAL_INTERVAL);
              interTrialIntervalWaitTime = POST_LAST_TRIAL_INTERVAL;
            }
          }

          /* INTER TRIAL INTERVAL LOOP
           * Do things during the inter-trial interval. For example,
           * continue to detect licks. Functions called during this
           * loop need to be agnostic to the trial time or to the fact
           * that a trial is happening, since there is no trial time
           * and a trial is not happening :)
           */
          print("Starting the inter-trial interval");
          if (IS_PRIMARY_RIG) {
            while (millis() - interTrialIntervalStartTime < interTrialIntervalWaitTime) {
              interTrialIntervalLoop();
            }
          } else {
            while (true) {
              interTrialIntervalLoop();
              if (checkSessionStart()) {
                break;
              }
            }
          }
          simulateButtonPress();

          // Any module called during the inter-trial interval loop
          // should be flushed afterwards, so it is ready for the next
          // trial.
          print("The inter-trial interval has ended");
          flushLickMetaData();
        }
      }
    }
  } else if (!sessionHasStarted) {
    rigOutsideSessionPause();
  } else {
    print("Your session has ended, but a sketch cannot stop Arduino.");
    print("Waiting a minute...");
    delay(60000);
  }

  // Checks for the session end
  if (currentTrial >= NUMBER_OF_TRIALS) {
    digitalWrite(PIN_MOUSE_LED, LOW);
    print("Session has ended");
    sessionHasEnded = true;
    digitalWrite(PIN_CAMERA, LOW);
    sessionEndTime = millis();
  }

  // If the session has ended and the `RIG_PERIODIC_RESET_TIME` has
  // passed again, we initiate a software reset
  if ((sessionHasStarted) && (sessionHasEnded) && (millis() - sessionEndTime > RIG_PERIODIC_RESET_TIME)) {
    rigSoftwareReset();
  }
}


/* RIG MANAGEMENT
 *
 */
bool checkSessionStart() {
  if (IS_PRIMARY_RIG) {
    if (digitalRead(PIN_BUTTON) == LOW) {
      return true;
    }
  } else {
    if (digitalRead(PIN_SECONDARY) == HIGH) {
      return true;
    }
  }
  return false;
}
void simulateButtonPress() {
  digitalWrite(PIN_SECONDARY, HIGH);
  // WARNING: this waits, to simulate a button press signal sent to
  // other rigs. Do not call `simulateButtonPress` during time-
  // sensitive operations!!!
  if (IS_PRIMARY_RIG) {
    delay(SECONDARY_PIN_PAUSE);
  } else {
    delay(SECONDARY_PIN_PAUSE-SECONDARY_RIG_PAUSE_OFFSET);
  }
  digitalWrite(PIN_SECONDARY, LOW);
}
void interTrialIntervalLoop() {
  // The `interTrialIntervalLoop` is called in two separate while loops
  // for primary and secondary rigs respectively, for now it is just
  // checking licks but if more inter-trial interval stuff needs to
  // happen it can be added here and not in two places above
  checkLick();
}
void rigOutsideSessionPause() {
  if (DEBUGGING) {
    // We do get stuck here, so consider setting `N_DEBUG_CYCLES` to
    // 0 to avoid this when you know your output pins are working
    if (N_DEBUG_CYCLES > 0) {
      print("Testing pins...");
      print("Air puff");
      debugCycleOutputPin(PIN_AIR_PUFF, N_DEBUG_CYCLES, DEBUG_CYCLE_DURATION);
      print("Water solenoid");
      debugCycleOutputPin(PIN_WATER_SOLENOID, N_DEBUG_CYCLES, DEBUG_CYCLE_DURATION);
      print("Positive tone");
      debugCycleOutputPin(PIN_TONE_POSITIVE, N_DEBUG_CYCLES, DEBUG_CYCLE_DURATION);
      print("Negative tone");
      debugCycleOutputPin(PIN_TONE_NEGATIVE, N_DEBUG_CYCLES, DEBUG_CYCLE_DURATION);
      print("Mouse LED");
      debugCycleOutputPin(PIN_MOUSE_LED, N_DEBUG_CYCLES, DEBUG_CYCLE_DURATION);
      print("Camera");
      debugCycleOutputPin(PIN_CAMERA, N_DEBUG_CYCLES, DEBUG_CYCLE_DURATION);
      print("Secondary rig 1");
      debugCycleOutputPin(PIN_SECONDARY, N_DEBUG_CYCLES, DEBUG_CYCLE_DURATION);
    }
    if (DEBUG_TEST_SECONDARY) {
      while (true) {
        print("Simulating button press...");
        delay(DEBUG_CYCLE_DURATION);
        simulateButtonPress();
      }
    }
  } else {
    print("Waiting for session to start...");
    delay(100);
  }
}
void debugCycleOutputPin(int pin, int n_cycles, int cycle_time) {
  // This is a debugging function to cycle an output pin on and off
  // for a given number of cycles. It is meant to be used when
  // developing the rig, not when running trials with a mouse in
  // training or testing
  for (int i = 0; i < n_cycles; i++) {
    print("Pin on");
    digitalWrite(pin, HIGH);
    delay(cycle_time);
    print("Pin off");
    digitalWrite(pin, LOW);
    delay(cycle_time);
  }
}
void rigSoftwareReset() {
  // Leave the rig in a good state, just in case something with the
  // software reset method used does not do so
  flushRigOutputPins();

  // It is actually a hardware reset right now, driven by software. But
  // perhaps this can be changed for a software-only reset
  digitalWrite(PIN_RESET, HIGH);
}
void flushRigOutputPins() {
  // If we move to a software-based reset, we want to make sure pins
  // do not get stuck in a bad state
  digitalWrite(PIN_AIR_PUFF, LOW);
  digitalWrite(PIN_CAMERA, LOW);
  digitalWrite(PIN_MOUSE_LED, LOW);
  digitalWrite(PIN_RESET, LOW);
  digitalWrite(PIN_SECONDARY, LOW);
  digitalWrite(PIN_WATER_SOLENOID, LOW);

  noTone(PIN_TONE_POSITIVE);
  noTone(PIN_TONE_NEGATIVE);
}


/* SESSION MANAGEMENT
 *
 */
void printSessionParameters() {
  // Add variables defined in `trial.h` or `rig.h` (or other) here.
  // That way, everything that defines the trial is recorded in case an
  // issue comes up later in the analysis

  // print("Session consists of:");
  vprint("NUMBER_OF_TRIALS", NUMBER_OF_TRIALS);
  vprint(TRIAL_TYPE_1, trialType1Idx);
  vprint(TRIAL_TYPE_2, trialType2Idx);
  vprint("trialTypesChar", trialTypesChar);

  // print("Printing Arduino or rig parameters");
  vprint("BAUD_RATE", BAUD_RATE);
  vprint("PIN_AIR_PUFF", PIN_AIR_PUFF);
  vprint("PIN_WATER_SOLENOID", PIN_WATER_SOLENOID);
  vprint("PIN_TONE_NEGATIVE", PIN_TONE_NEGATIVE);
  vprint("PIN_TONE_POSITIVE", PIN_TONE_POSITIVE);
  vprint("PIN_BUTTON", PIN_BUTTON);
  vprint("PIN_LICK", PIN_LICK);
  vprint("PIN_MOUSE_LED", PIN_MOUSE_LED);
  vprint("PIN_CAMERA", PIN_CAMERA);
  vprint("PIN_SECONDARY", PIN_SECONDARY);

  // print("Printing session parameters");
  vprint("DEBUGGING", DEBUGGING);
  vprint("IS_PRIMARY_RIG", IS_PRIMARY_RIG);
  vprint("NUMBER_OF_TRIALS", NUMBER_OF_TRIALS);
  vprint("IS_TRAINING", IS_TRAINING);
  vprint("TRAINING_TRIALS_ARE_REWARDED", TRAINING_TRIALS_ARE_REWARDED);
  vprint("INTER_TRIAL_DEBUG_WAIT_INTERVAL", INTER_TRIAL_DEBUG_WAIT_INTERVAL);
  vprint("TRIAL_DURATION", TRIAL_DURATION);
  vprint("LICK_TIMEOUT", LICK_TIMEOUT);
  vprint("LICK_COUNT_TIMEOUT", LICK_COUNT_TIMEOUT);
  vprint("WATER_REWARD_AVAILABLE", WATER_REWARD_AVAILABLE);
  vprint("WATER_DISPENSE_TIME", WATER_DISPENSE_TIME);
  vprint("WATER_DISPENSE_ON_NUMBER_LICKS", WATER_DISPENSE_ON_NUMBER_LICKS);
  vprint("WATER_TIMEOUT", WATER_TIMEOUT);
  vprint("USING_AUDITORY_CUES", USING_AUDITORY_CUES);
  vprint("AIR_PUFF_START_TIME", AIR_PUFF_START_TIME);
  vprint("AIR_PUFF_DURATION", AIR_PUFF_DURATION);
  vprint("INTER_PUFF_PAUSE_TIME", INTER_PUFF_PAUSE_TIME);
  vprint("AIR_PUFF_TOTAL_TIME", AIR_PUFF_TOTAL_TIME);
  vprint("AUDITORY_START", AUDITORY_START);
  vprint("AUDITORY_STOP", AUDITORY_STOP);
  vprint("POSITIVE_FREQUENCY", POSITIVE_FREQUENCY);
  vprint("POSITIVE_DURATION", POSITIVE_DURATION);
  vprint("AUDITORY_BUFFER", AUDITORY_BUFFER);
  vprint("NEGATIVE_FREQUENCY", NEGATIVE_FREQUENCY);
  vprint("NEGATIVE_PULSE_DURATION", NEGATIVE_PULSE_DURATION);
  vprint("NEGATIVE_CYCLE_DURATION", NEGATIVE_CYCLE_DURATION);
}


/* TRIAL MANAGEMENT
 *
 */
void trialStart() {
  print("Trial has started");
  trialHasStarted = true;

  // Lets mouse know water is available
  digitalWrite(PIN_MOUSE_LED, HIGH);

  // Check debugging
  if (DEBUGGING) {
    print("WARNING: DEBUGGING is set to true");
    print("This impacts the structure of the trial!!!!");
  }

  // At the start of each trial, define an inter-trial interval between 1min and 5min
  randomInterTrialInterval = random(MIN_ITI, MAX_ITI);

  // Prints out the trial-specific parameters. Other parameters are
  // printed at session start
  print("Printing trial parameters");
  vprint("randomInterTrialInterval", randomInterTrialInterval);

  currentTrialType = trialTypes[currentTrial];
  vprint("currentTrialType", currentTrialType);

  trialStartTime = millis();
}
void checkForTrialEnd() {
  if (millis() - trialStartTime > TRIAL_DURATION) {
    print("Trial has ended");
    trialHasEnded = true;
    digitalWrite(PIN_MOUSE_LED, LOW);
    trialEndTime = millis();
  }
}
void flushTrialMetaData() {
  currentTrial++;
  trialHasStarted = false;
  trialStartTime = __LONG_MAX__;
  trialHasEnded = false;
  trialEndTime = 0;
}


/* LICK MANAGEMENT
 * This includes dispensing water.
 *
 */
void checkLick () {
  int lickState = digitalRead(PIN_LICK);
  long currentLickTime = millis();
  long sinceLastLickTime = currentLickTime - lastLickTime;
  if (sinceLastLickTime > LICK_TIMEOUT) {
    if (lickState == HIGH) {
      lastLickTime = currentLickTime;
      isLicking = true;
      lickCount++;
      print("Lick");
      if (DEBUGGING) {
        vprint("lickCount", lickCount);
      }
    }
    if (lickState == LOW) {
      isLicking = false;
    }
  }
  if (sinceLastLickTime > LICK_COUNT_TIMEOUT) {
    if (lickCount > 0) {
      print("Resetting lick count");
      lickCount = 0;
    }
  }
}
void checkWater() {
  int waterState = digitalRead(PIN_WATER_SOLENOID);
  long currentWaterTime = millis();
  long sinceLastWaterTime = currentWaterTime - lastWaterTime;
  if (isLicking && (lickCount >= WATER_DISPENSE_ON_NUMBER_LICKS) && (waterState == LOW)) {
    if (sinceLastWaterTime > WATER_TIMEOUT) {
      // Only turn the water back on if the timeout has passed since the
      // last water turn on time
      digitalWrite(PIN_WATER_SOLENOID, HIGH);
      lastWaterTime = currentWaterTime;
      print("Water on");
    }
  } else if (waterState == HIGH) {
    if (sinceLastWaterTime > WATER_DISPENSE_TIME) {
      // Wait for the dispense time before turning it off
      digitalWrite(PIN_WATER_SOLENOID, LOW);
      print("Water off");
    }
  }
}
void flushLickMetaData() {
  lastLickTime = 0;
  isLicking = false;
  lastWaterTime = 0;

  digitalWrite(PIN_WATER_SOLENOID, LOW);
  print("Water off via trial flush");
}


/* AIR PUFF MANAGEMENT
 * Only on during CS+, but managed separate from auditory cue
 *
 */
void checkAir() {
  if (USING_AIR_PUFFS){
    bool isPuffing = digitalRead(PIN_AIR_PUFF);
    long currentTime = millis();
    long trialTime = currentTime - trialStartTime;
    if ((trialTime >= AIR_PUFF_START_TIME) && (trialTime < AIR_PUFF_TOTAL_TIME + AIR_PUFF_START_TIME)) {
      if (!isPuffing && ((currentTime - puffStopTime) > INTER_PUFF_PAUSE_TIME)) {
        digitalWrite(PIN_AIR_PUFF, HIGH);
        print("Puff start");
        puffStartTime = currentTime;
      }
      if (isPuffing && ((currentTime - puffStartTime) > AIR_PUFF_DURATION)) {
        digitalWrite(PIN_AIR_PUFF, LOW);
        print("Puff stop");
        puffStopTime = currentTime;
      }
    } else {
      // Makes sure we are not puffing
      if (isPuffing) {
        digitalWrite(PIN_AIR_PUFF, LOW);
        print("Puff stop, catch block");
        puffStopTime = currentTime;
      }
    }
  }
}
void flushAirPuffMetaData() {
  puffStartTime = __LONG_MAX__;
  puffStopTime = 0;

  digitalWrite(PIN_AIR_PUFF, LOW);
  print("Puff stop via trial flush");
}


/* POSITIVE SIGNAL
 *
 */
void checkPositiveSignal() {
  long trialTime = millis() - trialStartTime;
  if (!positiveSignalPlaying && (trialTime > AUDITORY_START) && (trialTime < (AUDITORY_STOP - AUDITORY_BUFFER))) {
    // Should only hit this code once per trial.
    // The buffer tries to prevent entering a second time, since:
    //
    //    POSITIVE_DURATION = AUDITORY_STOP - AUDITORY_START
    //
    tone(PIN_TONE_POSITIVE, POSITIVE_FREQUENCY, POSITIVE_DURATION);
    positiveSignalPlaying = true;
    positiveSignalStart = trialTime;
    print("Positive signal start");
  } else if (positiveSignalPlaying && ((trialTime - positiveSignalStart) > POSITIVE_DURATION)) {
    noTone(PIN_TONE_POSITIVE);
    positiveSignalPlaying = false;
    print("Positive signal stop");
  }
}
void flushPositiveSignalMetaData() {
  positiveSignalPlaying = false;
  positiveSignalStart = __LONG_MAX__;
  noTone(PIN_TONE_POSITIVE);
  print("Positive signal stop via trial flush");
}


/* NEGATIVE SIGNAL
 * This needs to pulse the tone, unlike positive. It only prints start
 * and stop during debugging because of the time prints can take
 *
 */
void checkNegativeSignal() {
  long trialTime = millis() - trialStartTime;
  if ((trialTime > AUDITORY_START) && (trialTime < (AUDITORY_STOP - AUDITORY_BUFFER))) {
    if (!negativeSignalPlaying && ((trialTime - negativeSignalStart) > NEGATIVE_CYCLE_DURATION)) {
      // This uses positive duration to see if the `noTone` below can turn the signal off
      tone(PIN_TONE_NEGATIVE, NEGATIVE_FREQUENCY, NEGATIVE_PULSE_DURATION);
      negativeSignalPlaying = true;
      negativeSignalStart = trialTime;
      print("Negative signal start");
    } else if (negativeSignalPlaying && ((trialTime - negativeSignalStart) > NEGATIVE_PULSE_DURATION)) {
      noTone(PIN_TONE_NEGATIVE);
      negativeSignalPlaying = false;
      negativeSignalStop = trialTime;
      print("Negative signal stop");
    }
  }
}
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

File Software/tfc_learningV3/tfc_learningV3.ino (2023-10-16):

// Maintainers:
// 1. @YuechengShi
// 2. @GergelyTuri
//
// This script is used in the learning phase of the task.
// Block: 4-6 trials
// inter-trial interval: 1-5 minutes
// Trial:
//   10s: Pre-CS      water on, report lick, no CS, no US
//   20s: CS          water on, report lick, CS on, no US
//   15s: trace       water on, report lick, no CS, no US
//   5s: US           water on, report lick, no CSk, US on
// CS+ continuous 10k HZ
// CS- Paulsed 2k HZ

// 1.Water droplit to the lick port
// 2.Auditory Cue + temporal delay
// 3.air puff solenoid valve
// 4.Lick port

#include "TimerControl.h"

TimerControl lickControl(12, INPUT);
TimerControl waterControl(5, OUTPUT);
bool isDispensing = false;  // shoudl this go to the fuction?

int buttonPin = 11;        //Define button pin to start trial.
int WaterSolenoidPin = 5;  //Define water pin.
int tonePinPositive = 10;  //Define Auditory cue pin.CS+
int tonePinNegative = 9;   //CS-
int AirpuffPin = 4;        //Air puff pin.
const int LickPin = 12;    // Define lick Pin.

unsigned long previousTime = 0;
const unsigned long preAuditoryCue = 1000;  //Wait 10 seonds at the begining of the trial before playing auditory cue.
unsigned long currentTime = 0;              //millis();
unsigned long toneDur = 2000;               //Tone duration.
int oldLickState = 0;
int sessStart = 0;

int trialStart = 0;
int ITI = 1000;  //Inter trial interval 10 seconds
long trialStartTime = 0;
int trialEndTime = 0;
long trialDur = 5000;  //trial duration

unsigned long PulsePreviousTime = 0;
const long PulseDuration = 100;
int randomValue = 0;  //Generate a random integer between 0 and 1.

int trialNum = 0;  //Initialize trial couner for trial counter.


//-------------------------------------------------------------------------------------------------------------------------------------------------------------------
void setup() {
  Serial.begin(9600);
  pinMode(buttonPin, INPUT_PULLUP);
  //1.
  pinMode(WaterSolenoidPin, OUTPUT);  //water output.
  //2.
  pinMode(tonePinNegative, OUTPUT);  //auditory cue output.
  pinMode(tonePinPositive, OUTPUT);
  //3.
  pinMode(AirpuffPin, OUTPUT);  //Airpuff output.
  //4.
  pinMode(LickPin, INPUT);  //input.
  digitalWrite(WaterSolenoidPin, LOW);
  digitalWrite(LickPin, LOW);
  randomSeed(A4);
}

//-------------------------------------------------------------------------------------------------------------------------------------------------------------------
void loop() {
  if (digitalRead(buttonPin) == LOW) {  // Start the trial when the button was pushed
    sessStart = 1;
    Serial.println("sess start");
  }
  if (sessStart == 1 && trialNum < 4) {  //Counter, 4 trails in one block.
    currentTime = millis();
    checkTrial();
    isLicking();
    waterDispensing(isLicking());
    checkCue();
  }
}

//Trial start-----------------------------------------------------------------------------------------------------------------
void checkTrial() {
  //Serial.print(currentTime);
  if (trialStart == 0 && millis() - trialEndTime > ITI) {  // to start new trial
    trialStart = 1;
    randomValue = random(2);  // pick new rand num (0/1) each trial
    Serial.println("new Trial");
    Serial.print("trialStart, trialType=");
    Serial.print(randomValue);
    Serial.print(", ms=");
    Serial.println(millis());
    trialStartTime = millis();
    trialNum = trialNum + 1;  // Trial counter starts counting
    Serial.print(trialNum);
  }
  if (trialStart == 1 && millis() - trialStartTime > trialDur) {  //Ends trial after 50s
    trialEndTime = millis();
    trialStart = 0;
  }
}

//Lick and water--------------------------------------------------------------------------------------------------------------------
bool isLicking() {
  unsigned long timeOutDuration = 100;
  int LickState = digitalRead(LickPin);  // Read the lick sensor state.
  if (LickState == HIGH) {
    unsigned long lickTime = millis();
    Serial.println("Lick on, ms " + String(lickTime));
    lickControl.timeOut(timeOutDuration);
    return true;
  } else {
    return false;
  }
}

void waterDispensing(bool isDispensing) {
  if (isDispensing) {
    unsigned long timeOnDuration = 200;
    unsigned long waterOn = millis();
    digitalWrite(WaterSolenoidPin, HIGH);
    Serial.println("water on, ms " + String(waterOn));
    waterControl.timeOn(timeOnDuration);
    digitalWrite(WaterSolenoidPin, LOW);
    Serial.println("water off, ms " + String(millis()));
    isDispensing = false;
  }
}
//Auditory cue and airpuff ---------------------------------------------------------------------------------------------------------------------------------------------
void checkCue() {
  if (trialStart == 1 && millis() - trialStartTime >= preAuditoryCue) {
    //Serial.print("toneCueOn, ms=");  //indicate when cue starts playing.
    // Serial.println(millis());        //indicate when cue starts playing
    Cue();
    airPuff();
  }
}

//Auditory cue---------------------------------------------------------------------------------------------------------------------------------
void Cue() {
  // Serial.println(randomValue);
  if (randomValue == 1 && millis() - trialStartTime < toneDur) {  //CS-, Pulsed 2K Hz
    if (millis() - PulsePreviousTime > 2 * PulseDuration) {
      tone(tonePinNegative, 2000, PulseDuration);
      PulsePreviousTime = millis();
      Serial.print("pulse");
      Serial.print(millis());
    }

  } else if (randomValue == 0 && millis() - trialStartTime < toneDur) {  //CS+, continuous 10K Hz
    noTone(tonePinNegative);
    tone(tonePinPositive, 10000, toneDur);
  }

  if (millis() - trialStartTime > trialDur) {  //stops tone after playing for 20s.
    noTone(tonePinNegative);
    noTone(tonePinPositive);
    trialEndTime = millis();
  }
}
//Air Puff---------------------------------------------------------------------------------------------------------------------------------------------------------------
void airPuff() {
  static int trialStartTime = 0;  // For example
  static int allPuffsStartTime = 35000;
  static int nPuffs = 5;
  static int puffDuration = 200;
  static int puffPauseTime = 1000;
  static int airpuffTotalDuration = puffDuration * nPuffs + puffPauseTime * (nPuffs - 1) + 100;
  bool puffing = false;
  int puffStopTime = 0;
  int puffStartTime = 0;
  if (currentTime - trialStartTime >= allPuffsStartTime && currentTime - trialStartTime < airpuffTotalDuration + allPuffsStartTime) {
    if (puffing == false && currentTime - puffStopTime > puffPauseTime) {
      digitalWrite(AirpuffPin, HIGH);
      puffing = true;
      puffStartTime = currentTime;
    }
    if (puffing == true && currentTime - puffStartTime > puffDuration) {
      digitalWrite(AirpuffPin, LOW);
      puffing = false;
      puffStopTime = currentTime;
    }
  } else {
    // Make sure we are not puffing
    if (puffing == true) {
      digitalWrite(AirpuffPin, LOW);
      puffing = false;
      puffStopTime = currentTime;
    }
  }
}

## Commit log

2023-08-17 basic components
    [clamp_of_clamp_v2.stl, clamp_v2_1inch_slot.stl, clamp_v2_1inch_slot_v1.ipt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]
2023-08-17 organizing things
    [Body chamber.obj]
2023-09-11 Create sketch_aug31a.ino
    Arduino Code version 1
2023-10-10 Change water solenoid to open only when licked
2023-10-19 Basic sketch to test Arduino itself
2023-10-19 Simple button press sketch
2023-11-02 Fixes testing with rig
    [Rig.ino, trial.h]
2023-11-07 Processing script prototype
2023-11-09 Add Arduino serial communication code and update .gitignore
2023-11-10 Refactor serial communication code for better error handling and data parsing
    [py_arduino_serial.py, py_arduino_simple.py]
2023-11-20 Add camera control functionality
2023-11-20 Fix camera binding issue, adding test video
2023-11-29 Maybe this can daisy-chain rigs?
2023-11-29 Update pin assignments for camera and LED update pin assigment list in docs
2023-11-30 Daisy chain rig tested working, and other debugging
2023-12-02 Updates to rig daisy chaining with some docs
2023-12-02 update readme with attempts to reset arduino before running code
    [Rig.ino]
2023-12-02 Fix missing semicolon in checkSessionStart function
    [Rig.ino]
2023-12-02 Implement a software reset, using a connection to the reset pin
    [Rig.ino, rig.h, trial.h]
2023-12-02 No need to set the secondary pin to high on start
2023-12-03 making py_arduino_serial capable of handling multiple arduinos
2023-12-04 Fixed time after last trial
    [Rig.ino, trial.h]
2023-12-04 Fix missing semicolon in inter-trial interval wait time calculation
    [Rig.ino]
2023-12-05 Refactor print_trial_data function to session_summary -- WIP
2023-12-12 adding body chamber components
2023-12-12 renaming a file
    [Body chamber_CL.obj]
2023-12-12 name change
    [Body chamber.obj]
2023-12-29 Update camera_class.py and camera_control.py scripts WIP
2023-12-29 Update camera_class.py and camera_control.py dual recording seems to be working now
2024-01-01 Refactor serial port handling and add optional secondary port
    This commit refactors the code for handling serial ports in the `py_arduino_serial.py` file. The `secondaryport1` argument is now optional, allowing for communication with a secondary Arduino if prov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
2024-01-01 Refactor camera setup and add optional camera arguments
2024-01-02 Refactor code and add camera control functionality
2024-01-05 Update README.md with project description, repository structure, and software installation instructions. Add documentation for data collection and camera control.
2024-01-19 adding varioius hardware components
    [LED holder.step]
2024-04-07 fix regex, partition code, update documentation, add validation and additional ino fields
    [py_arduino_serial_GUI.py, update_sketch.py]
2024-04-08 Patches print function
2024-04-11 See if printing works over logging
2024-04-19 Option to filter for water on
2024-04-26 Print a msg if unbalanced data is detected
2024-04-26 Option for verbose analysis printing
2024-04-26 Filter for a tail of sessions
2024-05-07 Printing entire data sets does not make sense
2024-05-07 Round printout
2024-05-10 Print out learning rates
2024-05-30 Attach session plot to analysis object
2024-07-31 Trial cap increased to 30, Fixed buggy print statements
    [Rig.ino, py_arduino_serial_GUI.py, trial.h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]
2024-08-02 Add Arduino shield and body chamber laser cut parts
2024-08-05 Do not print every scalar divide error
2024-08-06 Fix printing
2024-08-06 Tweak the bad blob filter
2024-08-07 Update print and vprint overloading
2024-08-16 Update Arduino shield design to latest version
2024-09-06 Better filter on trial type mismatch
2024-09-06 Note on heat map method
2024-12-05 minor housekeeping
    [Body chamber_CL.obj]
2024-12-12 Remove debug print statement
2024-12-18 track trace data
2024-12-20 trace learning rate
2025-01-04 Allow filtering analysis by cohort, and some other stuff
2025-02-21 Add Session data class and prototype notebook for session data analysis
2025-02-24 pre-cs, tone, trace, puff, iti data
2025-02-28 ITI prints
2025-03-04 Update 'prePrint' so the millis and trial time use the same millis
2025-03-12 Fix trial time printing and water training (#91)
    [Rig.ino]
2025-04-03 change trial stage duration extraction method
